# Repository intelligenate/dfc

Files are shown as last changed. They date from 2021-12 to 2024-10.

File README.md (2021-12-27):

# DFC - Data Fitness Connector

Free your data! 

DFC allows the Peloton Bike to communicate with fitness watches, head units, and apps — a feature that’s not available on the stock Bikes. It reads power and cadence data in real-time, through a cable connected to your bike, and broadcasts them wirelessly to nearby devices including those built around platforms like Zwift and Garmin. This lets you enjoy the built-in functionality of your bike while simultaneously utilizing features and services that depend on third-party platforms.

* Supports two simultaneous wireless connections for connecting to both a wearable and app at the same time
* Wireless device firmware updates for future upgrades
* Open and expandable platform for adding new features down the line

This repository is the home to the open design files for DFC. 

DFC can be ordered from the [Crowd Supply page here](https://www.crowdsupply.com/intelligenate/data-fitness-connector) and more information on DFC can be found on [our website](https://intelligenate.com/dfc.html).

See the [User Guide](https://github.com/intelligenate/dfc/blob/main/docs/user-guide.md) for details on how to setup and use DFC.

# Notice

DFC is a product of Intelligenate, LLC. DFC is not affiliated with Peloton Interactive, Zwift, Garmin or any other company mentioned in this repository. All trademarks are the property of their respective owners.

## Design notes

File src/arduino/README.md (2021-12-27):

# IrieTron 3030 Arduino Notes

The IrieTron 3030 Arduino file is what the initial development of DFC was done with. It is made to use with the Adafruit Bluefruit Feather board with a MAX3222 RS-232 driver/receiver IC on a FeatherWing. The Arduino version is no longer in active development and is provided to others who may want to make their own data broadcaster.

# Schematic

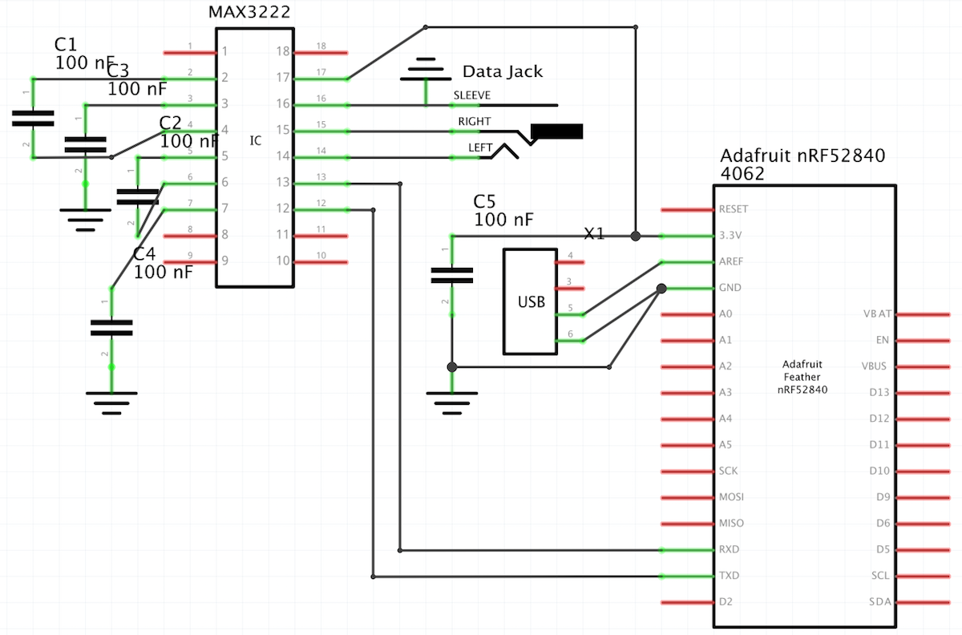
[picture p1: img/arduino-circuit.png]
arduino-circuit


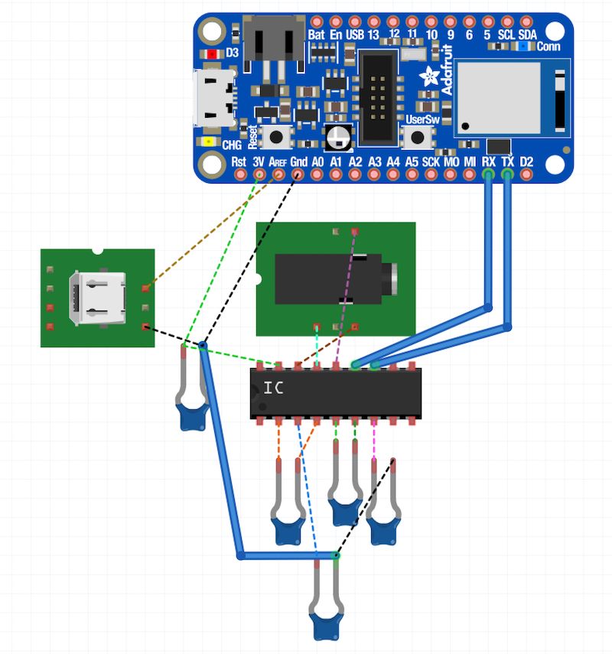
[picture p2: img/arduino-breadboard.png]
arduino-breadboard


# Bill of Materials

| Part | Quantity |
| --- | --- |
| 100nF Capacitor | 5 |
| Adafruit Bluefruit Feather | 1 |
| 3.5mm Jack | 1 |
| USB Connector | 1 |
| MAX3222 RS-232 driver/receiver IC | 1 |

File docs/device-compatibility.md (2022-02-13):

| Manufacturer | Model | Type | Power & Cadence | Speed & Cadence Only Beta | Notes |
| --- | ----- | ---- | --- | --- | ----- |
| Garmin | Fenix 6X, 6 Pro, 6 Saffire | Watch | Yes | Yes | |
| Garmin | Fenix 6, Fenix 6S | Watch | Yes* | | *Dropouts were causing issues with the base Fenix 6 models. Try [this update](https://github.com/intelligenate/dfc/releases/tag/power-cadence-beta.3) for a fix. See the [Firmware Updates](#firmware-updates) section below for details on updating. |
| Garmin | Fenix 5X | Watch | Yes | | |
| Garmin | Marq | Watch | Yes | | |
| Garmin | FR945 | Watch | Yes | | |
| Garmin | Venu, Insight | Watch | No | | These watches do not support reading power data from *any* manufacturer but speed and cadence should work |
| Garmin | Vivoactive 4 | Watch | No | Yes | These watches do not support reading power data from *any* manufacturer but speed and cadence should work |
| Garmin | FR645, FR245 | Watch | No | | These watches do not support reading power data from *any* manufacturer but speed and cadence should work |
| Polar | Grit X, Vantage | Watch | Yes | | |
| Cronos | Pace | Watch | Yes | | |
| Garmin | Edge 130, 530, 830 | Cycling Computer | Yes | Yes | |
| Stages Dash | M50, L50 | Cycling Computer | Yes | Yes | |

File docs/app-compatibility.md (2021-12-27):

| Application | Power & Cadence | Notes |
| --- | --- | ----- |
| Zwift | Yes | |
| TrainerRoad | Yes | |
| Sufferfest  | Yes | |
| Kinomap | Yes | |
| Wahoo | Yes | |

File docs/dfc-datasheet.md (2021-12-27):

# DFC Datasheet

DFC by Intelligenate

### Technical Specifications

- Built around an ARM Cortex-M4 32-bit processor with a 2.4 GHz transceiver
- 11 exposed GPIO pins in a breadboard- and IDC-compatible layout
    - 4 analog or digital pins
    - 7 digital-only pins
- 16 M-Bit QSPI external flash memory
- Two channels of bi-directional RS-232-to-TTL/CMOS conversion via MAX3222 IC
- I²C JST connector compatible with SparkFun's Qwiic or Adafruit STEMMA QT Connect System 
- SWD connections on the front and back of the board via Tag Connect footprints for firmware programming and debugging
- 20 V max to 3.3 V voltage regulator
- Two 3.5 mm stereo jacks connected to one another and to the RS-232 driver/receiver IC.
    - An off-by-default jumper allows the transmission of RS-232 data through the jacks
- Two USB Type-C connectors that allow DFC to be placed in-line with a USB cable operating at up to 20 V
    - This experimental, use-at-your-own-risk configuration allows you to branch off signals present in the USB cable—such and connect them to the processor
    - Configurable routes via jumper headers and solder pads for USB D+/- and SBU1/2

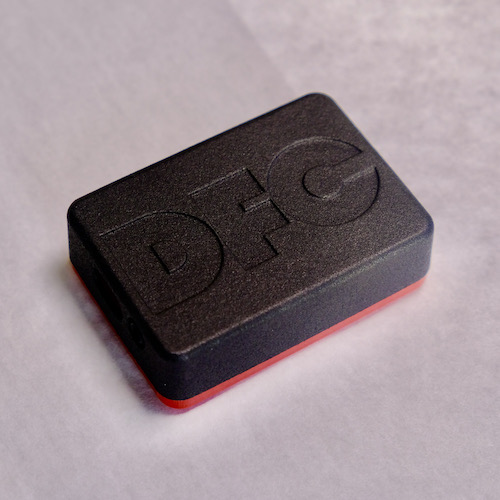
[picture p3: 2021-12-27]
img/dfc-production_sm.jpeg

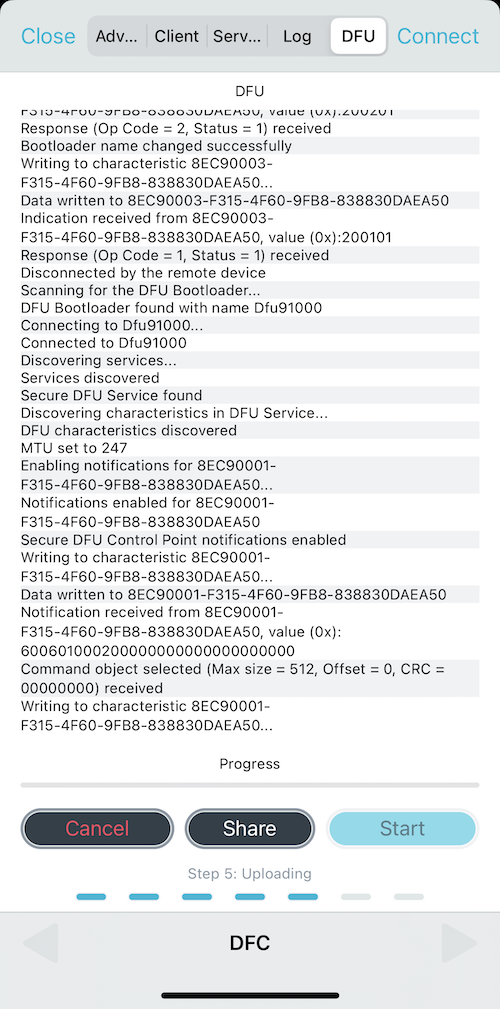
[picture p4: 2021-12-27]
img/firmware_update/DFC_fw_5.png

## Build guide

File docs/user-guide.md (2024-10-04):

# DFC User Guide

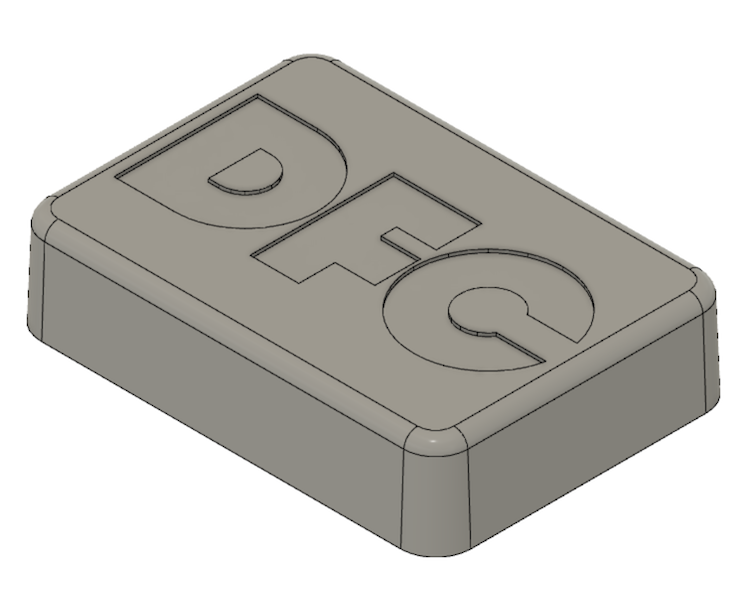
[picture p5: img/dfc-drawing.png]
dfc-drawing


# Features

DFC allows the Peloton Bike to communicate with fitness watches, head units, and apps — a feature that’s not available on the stock Bike. It reads power and cadence data in real-time, through a cable connected to your bike, and broadcasts them wirelessly to nearby devices including those built around platforms like Zwift and Garmin. This lets you enjoy the built-in functionality of your bike while simultaneously utilizing features and services that depend on third-party platforms.

* Supports two simultaneous wireless connections for connecting to both a wearable and app at the same time
* Wireless device firmware updates for future upgrades
* Open and expandable platform for adding new features down the line

# Connecting DFC to your bike

Hooking up DFC only takes a few minutes to get going and no cable-cutting or permanent modifications to the bike or tablet are necessary. Refer to the connection diagram for these steps.

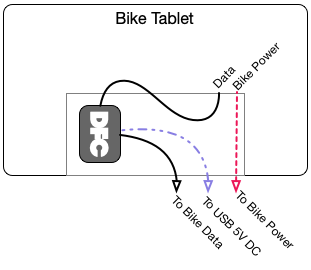
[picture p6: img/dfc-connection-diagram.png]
dfc-connection-diagram


1. Disconnect the data cable from the back of the tablet and plug it into either jack on DFC.
    1.  Two cables are on the back of the tablet – the one on the left is the data cable and the one on the right is the power cable. 
    2.  The data cable and power cable are held to the back of the tablet by a clasp that must be disengaged prior to removing the data cable.
    3.  DFC has two jacks that look similar to the ones you might use to plug in headphones, plug the data cable into either one.
2. Connect the provided short data cable between DFC and the data connection on the back of the tablet. Either data jack on DFC can be used for this connection.
3. Connect the provided long USB power cable to DFC.
    1. Either of the two USB-C ports on DFC can be used for this connection.
4. Connect the provided long USB power cable to a USB charging outlet. A USB charging outlet is not provided but most standard USB chargers such as those used to charge phones and other devices should work. 
    1.  NOTE: DFC must be powered with a USB-C to USB-A cable such as the one provided. It is not supported to work with a USB-C to USB-C cable.
    2.  DFC has two USB ports but only one is to be connected at a time. The multiple ports allow flexibility in placement and cable routing as well as future expansion options.
5. Recommended: Attach DFC to the back of your tablet with mounting tape or mounting putty. Use zip-ties to run the DFC power cable along the path of your bike's power cable for a clean look.
6. **Note: Make sure all the cables are pushed in fully before proceeding.**

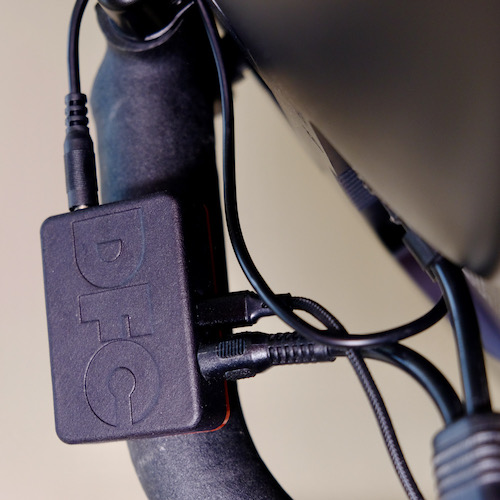
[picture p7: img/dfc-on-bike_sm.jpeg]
dfc-on-bike_sm


# Connecting to DFC with your device or app

1. Follow the directions from your specific application or device for pairing a sensor. See the [Compatibility Tables](#compatibility-table) for apps and devices that are known to work, or not, with DFC.
    1. DFC acts as a power meter and cadence sensor and will show up in the pairing screen or sensors section of the application/device you are connecting to. 
    2. For example, in Zwift in the Paired Devices menu: (1) click Power Source and select DFC, then (2) click Cadence and select DFC.
    3. For example, on a Garmin cycling computer or Fenix watch go to Settings > Sensor > Add Sensor and you will see DFC show up as a power sensor. Once selected your device will also read cadence from DFC with no additional setup required.
2. Once you do the initial pairing your device will connect to DFC automatically every time you start a ride.
3. Note: DFC only receives data when live power data is shown on the tablet screen. 
    1. Your connected device can start recording data before the class starts as long as the power/watts are displayed on the tablet screen. This allows you to string a few classes together and have them show up as one workout on your device.

# Troubleshooting

* DFC is not showing up on my device or app's pairing screen.
    * Verify that DFC is powered on. It will blink once per second for the first three minutes it’s powered on. You can see the blinking through the ports.
    * Some users have had trouble with using USB-C to USB-C power supplies. DFC draws so little power that they don't think anything is there and they shut down. For best results, use a power supply that works with the cable that DFC came with.
    * Some Garmin devices require a firmware update. [Try this update](https://github.com/intelligenate/dfc/releases/tag/power-cadence-beta.4) to fix it. See the [Firmware Updates](#firmware-updates) section below for details on updating.
* DFC is connected to my device or app but not showing any power data on my connected device.
    * Verify that all connections on DFC and your tablet are tight.
    * Verify that the screen on your tablet shows your power and other metrics.
    * Your tablet must be in a class or set to just ride a scenic or self-paced ride for DFC to receive data. 
* DFC is connected to my device or app but the tablet screen does not show any power data.
    * Verify that all connections on DFC and your tablet are tight.
    * Check the tablet screen for messages stating that there are loose connections. If so, recheck all connections. If there are no messages on the tablet screen then exit and restart the class you were doing.

# Compatibility Tables

Most modern devices and apps that support reading power data *should* work with DFC. Please note that DFC is not compatible with legacy devices that only support the the ANT+ protocol such as the Garmin Fenix 5 and Wahoo Roam v1 (2019). 

These tables are updated to show whether something is known to work with DFC (or not).

## Devices

| Manufacturer | Model | Type | Power & Cadence | Speed & Cadence Only Beta | Notes |
| --- | --- | --- | --- | --- | --- |
| Apple | Watch with WatchOS 10+ | Watch | Yes | Yes | Apple Watches with WatchOS 10+ work with DFC. [See here](https://www.dcrainmaker.com/2023/07/apple-watch-power-meters-support-everything-wanted.html) for how to set it up. |
| Garmin | Fenix 7, 7S | Watch | Yes | Yes | *A watch beta in early 2024 was causing issues with these. [This update](https://github.com/intelligenate/dfc/releases/tag/power-cadence-beta.4) fixes it. See the [Firmware Updates](#firmware-updates) section below for details on updating.* |
| Garmin | Epix (gen 2), Epix Pro | Watch | Yes | Yes | *A watch beta in early 2024 was causing issues with these. [This update](https://github.com/intelligenate/dfc/releases/tag/power-cadence-beta.4) fixes it. See the [Firmware Updates](#firmware-updates) section below for details on updating.* |
| Garmin | Fenix 6X, 6 Pro, 6 Saffire | Watch | Yes | Yes | |
| Garmin | Fenix 6, Fenix 6S | Watch | Yes* | | *Dropouts were causing issues with the base Fenix 6 models. [This update](https://github.com/intelligenate/dfc/releases/tag/power-cadence-beta.4) fixes it. See the [Firmware Updates](#firmware-updates) section below for details on updating.* |
| Garmin | Fenix 5X | Watch | Yes | | |
| Garmin | Marq | Watch | Yes | | |
| Garmin | FR945 | Watch | Yes | | |
| Garmin | FR265 | Watch | Yes | | *A watch beta in early 2024 was causing issues with these. [This update](https://github.com/intelligenate/dfc/releases/tag/power-cadence-beta.4) fixes it. See the [Firmware Updates](#firmware-updates) section below for details on updating.* |
| Garmin | FR935 | Watch | No | | |
| Polar | Grit X, Vantage | Watch | Yes | | |
| Cronos | Pace | Watch | Yes | | |
| Garmin | Venu, Insight | Watch | No | | These watches do not support reading power data from *any* manufacturer but speed and cadence should work |
| Garmin | Venu 3 | Watch | No | Yes | Garmin states that the Venu 3 supports power meters but it appears only ANT+ power meters are supported and DFC does not broadcast ANT+. The Venu 3 does support the speed and cadence beta firmware. See the [Firmware Updates](#firmware-updates) section below for details on updating. |
| Garmin | Vivoactive 4 | Watch | No | Yes | These watches do not support reading power data from *any* manufacturer but speed and cadence should work |
| Garmin | FR645, FR245 | Watch | No | | These watches do not support reading power data from *any* manufacturer but speed and cadence should work |
| Garmin | 735XT, Fenix 3 | Watch | No | | These watches only support the ANT+ wireless protocol which is not compatible with DFC |
| Garmin | Edge 130, 530, 830 | Cycling Computer | Yes | Yes | |
| Stages Dash  | M50, L50 | Cycling Computer | Yes | Yes | |
| Wahoo | Roam v2 (2022) | Cycling Computer | Yes | Yes | |
| Wahoo | Roam v1 (2019) | Cycling Computer | No | No | This device only supports the ANT+ wireless protocol which is not compatible with DFC |
## Apps

| Application | Power & Cadence | Notes |
| --- | --- | ----- |
| Zwift | Yes | |
| TrainerRoad | Yes | |
| Sufferfest  | Yes | |
| Kinomap | Yes | |
| Wahoo | Yes | |
| ROUVY | Yes | |

# Firmware Updates

Firmware updates are [located here](https://github.com/intelligenate/dfc/releases). To update the firmware or try out a beta release follow these steps.

1. Download the nRF Connect app for [iOS](https://apps.apple.com/us/app/nrf-connect-for-mobile/id1054362403) or [desktop](https://www.nordicsemi.com/Products/Development-tools/nrf-connect-for-desktop). Please note that the desktop version requires the use of a $10 USB dongle [available here](https://www.mouser.com/ProductDetail/Nordic-Semiconductor/nRF52840-Dongle?qs=gTYE2QTfZfTbdrOaMHWEZg%3D%3D). 
    * nRF Connect is a third-party app developed by the maker of the wireless chipset used in DFC. It allows you to perform wireless firmware updates on DFC.
    * Some users have reported issues using the [nRF app for Andriod](https://play.google.com/store/apps/details?id=no.nordicsemi.android.dfu&hl=en_US&gl=US&pli=1), given this we recommend the iOS app.

2. Download the firmware you want to install [from here](https://github.com/intelligenate/dfc/releases). 

    * Firmware releases are packaged as zip files. The latest, most compatible, releases are marked "Latest".

    * Releases marked "Pre-release" contain new features that may or may not work with some devices. 

    * If the new features on a pre-release build don't work with your device you can always go back to a stable release by downloading and installing the release marked "Latest".

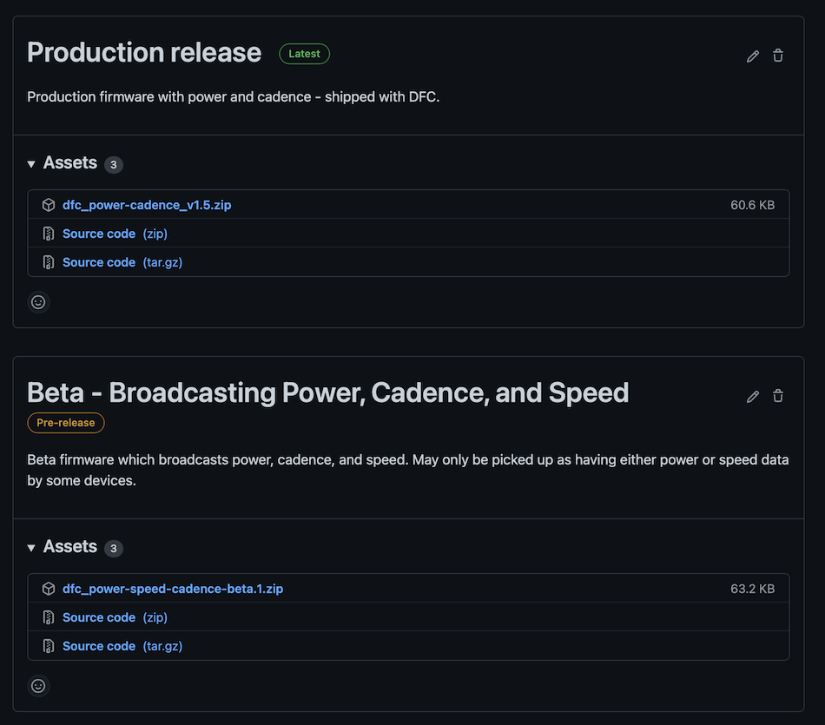
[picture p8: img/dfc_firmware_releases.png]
dfc_firmware_releases
    

3. Connect to DFC with nRF Connect.

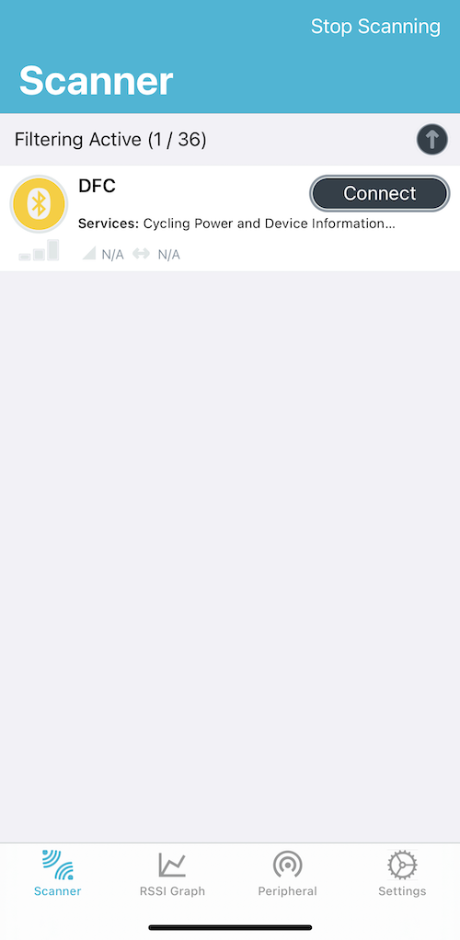
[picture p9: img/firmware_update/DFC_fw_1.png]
DFC_fw_1
    

4. Once connected go to the DFU tab on the top.

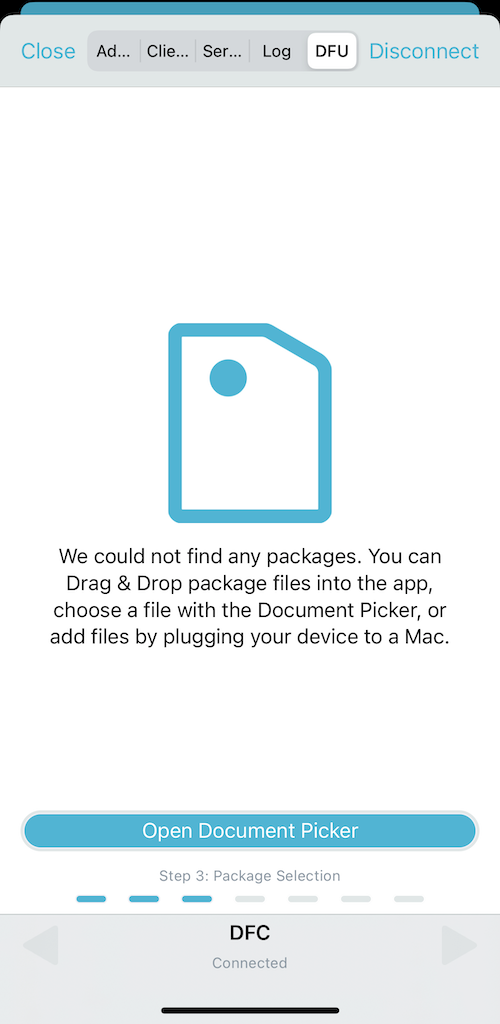
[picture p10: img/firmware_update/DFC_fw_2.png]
DFC_fw_2
    
    
5. Click Open Document Picker and select the firmware file downloaded earlier [from here](https://github.com/intelligenate/dfc/releases).

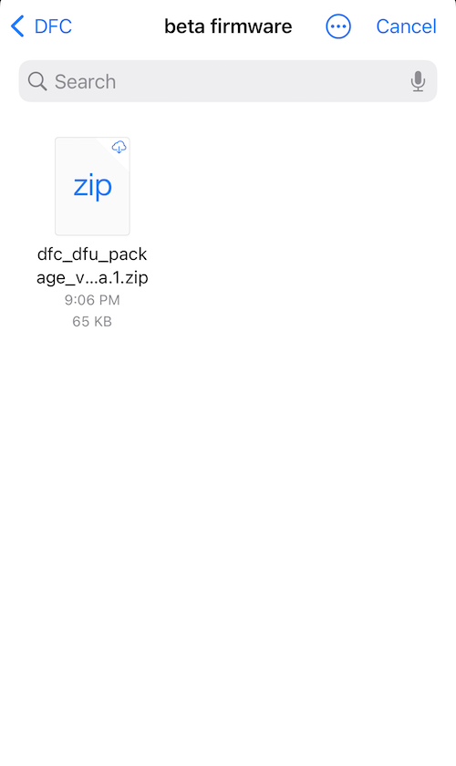
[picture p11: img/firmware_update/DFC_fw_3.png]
DFC_fw_3
    

6. After the file is loaded press Start to upload it to DFC.

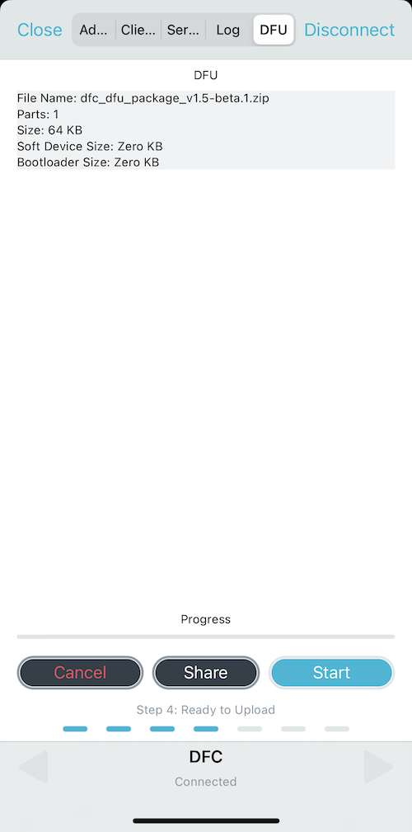
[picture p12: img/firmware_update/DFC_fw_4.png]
DFC_fw_4
    

7. After the update is completed you'll see the image below and can close nRF Connect.

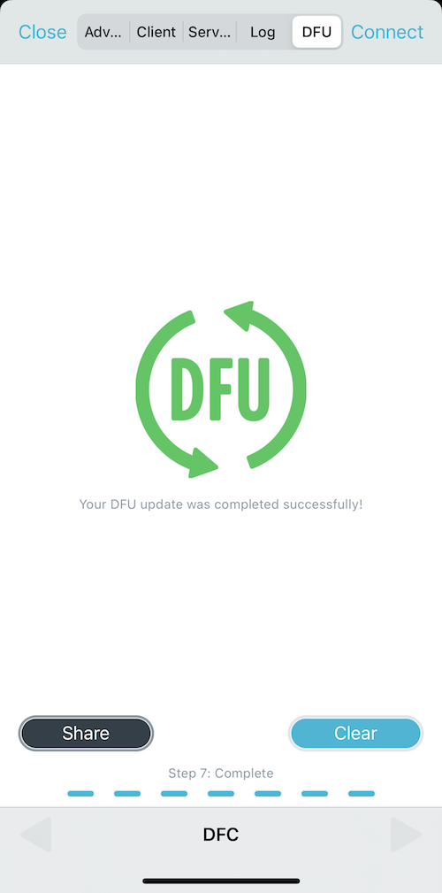
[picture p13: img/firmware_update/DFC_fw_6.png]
DFC_fw_6
    

# Upcoming Features

## Addition of speed sensor capability

We have a prototype of this working but testing with several fitness devices revealed some undesired behavior. Some devices only pick up either power data or speed data but not both.  We're working on this and will include an update once we get it working consistently across devices.

Adventurous users are welcome to try out the [beta releases here](https://github.com/intelligenate/dfc/releases). If you do so please report back what device you used and whether all the features worked. See the [Firmware Updates](#firmware-updates) section for details on how to update the firmware. After trying a beta release you can always revert back to the production release.

# FAQs

## Can I power DFC with the micro-USB connector on the back of the tablet?

While most USB-C to micro-USB cables don't allow for power going in that direction some users report that USB-OTG cables [such as this one](https://www.amazon.com/dp/B07KP6NTK7) may work. Additionally others have had success with using an [adapter like this](https://www.amazon.com/dp/B01LYYAOIE/) to plug into the back of the tablet, then use the cable that came with DFC to plug into that adapter. For those in Europe [this adapter](https://www.amazon.de/dp/B0BKPZD24M) has also been reported to work.

Down the road another option is that DFC can run on a coin cell battery but it's not optimized for that yet. It only lasts for a couple days instead of a few months so it's not advised to try it until it's working well. That would allow for a cleaner connection and no additional cord to run.

## Does DFC work with the Bike+?

DFC was designed to be compatible with the original Peloton Bike and is only supported for use with that model. Initial testing with the Bike+ has found that it's going to be infeasible at this time to support it.

# Notice

DFC is a product of Intelligenate, LLC and is designed and assembled in USA.

DFC is not affiliated with Peloton Interactive, Zwift, Garmin or any other company mentioned here. All trademarks are the property of their respective owners.

This user guide is released with a [CC BY-SA license](https://creativecommons.org/licenses/by-sa/4.0/).  

# Warnings, Regulatory Compliance, and Safety Information

## WARNINGS

* This product shall only be connected to an external USB power supply rated at 5-20V DC. Any external power supply used with DFC shall comply with relevant regulations and standards applicable in the country of intended use.
* In testing DFC no adverse incidents, to equipment or otherwise, connected to its use have been observed. In no event shall Intelligenate, LLC be liable for any direct, indirect, punitive, incidental, special consequential damages, to property or life, whatsoever arising out of or connected with the use or misuse of our products.

## INSTRUCTIONS FOR SAFE USE

To avoid malfunction or damage to your DFC please observe the following:
* Do not expose it to water or moisture while in operation.
* Take care while handling to avoid mechanical or electrical damage to the printed circuit board and connectors.

## COMPLIANCE INFORMATION

DFC complies with the relevant provisions of the European RoHS Directive 2011/65/EU, 2015/863/EU and Radio Equipment Directive (RED) 2014/53/EU. In common with all Electronic and Electrical products DFC should not be disposed of in household waste. Alternative arrangements may apply in other jurisdictions.

## FCC Statement

This device complies with part 15 of the FCC Rules. Operation is subject to the following two conditions: (1) This device may not cause harmful interference, and (2) this device must accept any interference received, including interference that may cause undesired operation.

## ISED Statement

This device complies with Industry Canada license exempt RSS standard(s). Operation is subject to the following two conditions: (1) this device may not cause interference, and (2) this device must accept any interference, including interference that may cause undesired operation of the device. 
Le présent appareil est conforme aux CNR d'Industrie Canada applicables aux appareils radio exempts de licence. L'exploitation est autorisée aux deux conditions suivantes: (1) l'appareil ne doit pas produire de brouillage, et (2) l'utilisateur de l'appareil doit accepter tout brouillage radioélectrique subi, même si le brouillage est susceptible d'en compromettre le fonctionnement. 

# SICHERHEITSANWEISUNGEN 

## WARNUNGEN UND HINWEISE 

* Dieses Produkt darf nur an eine externe Stromquelle mit einer Nennspannung von 5-20 V Gleichstrom. Alle mit dem DFC verwendeten externen Stromquellen müssen den betreffenden Vorschriften und Regelwerken des Nutzungslandes entsprechen. 
* Beim Testen von DFC wurden keine nachteiligen Vorkommnisse an Geräten oder auf andere Weise im Zusammenhang mit seiner Verwendung beobachtet. In keinem Fall haftet Intelligenate, LLC für direkte, indirekte, strafrechtliche, zufällige oder besondere Folgeschäden an Eigentum oder Leben, die sich aus oder im Zusammenhang mit der Verwendung oder dem Missbrauch unserer Produkte ergeben.

# RICHTLINIEN FÜR DEN SICHEREN GEBRAUCH 

Bitte halten Sie sich an die folgenden Anweisungen, um Fehlfunktionen oder Schäden an Ihrem DFC zu vermeiden: 
•   Setzen Sie das Gerät nie Wasser oder Feuchtigkeit aus und setzen Sie es nicht auf einer leitenden Oberfläche ab, während es in Betrieb ist. 
•   Seien Sie bei der Arbeit mit dem Gerät und dessen Handhabung vorsichtig, um mechanische oder elektrische Schäden an der Leiterplatte und an den Anschlüssen zu vermeiden. 

## COMPLIANCE-INFORMATIONEN

Das DFC entspricht den relevanten Bestimmungen für die europäische Union RoHS Directive 2011/65/EU, 2015/863/EU & Radio Equipment Directive (RED) 2014/53/EU. Wie alle anderen Elektro- und Elektronikprodukte (EEE) auch, darf das DFC nicht als Hausmüll entsorgt werden. In anderen Gesetzgebungen können alternative Regelungen gültig sein.
<hr>

CE_FCC

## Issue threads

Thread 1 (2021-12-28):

Beta Firmware - Feedback Report

htims05, 2021-12-28:
Hi - I tried the beta firmware to see if my watch would pick up the speed from the peloton.  Sorry to report but in my case the beta firmware seemed no different than the latest production version.  Meaning it still showed cadence and power but not speed.  This was using a Coros Pace 2 Watch as well as the Wahoo Fitness app on iOS (ver 14.8.1).

I'm not sure if this is the correct spot to post this but it looked like the only place to post feedback.

DangerP6, 2021-12-29:
On the production software, it passed the power data with no issues, however there was  no speed/distance data passed from the DFC/Peloton though the Garmin Fenix 6 watch. Thanks!

LeitoRodz, 2021-12-29:
Hi there,

Happy to report that power and cadence reports without issues on both production and beta FWs. No success on getting speed on the pre-released version.

Device: Garmin Forerunner 945
Software Version (Garmin device): 8.20 (28b18b9)

doudar, 2021-12-30:
A lot of BLE ftms devices don't report speed because real world speed is a product of your weight, rolling resistance, incline and drag. It's typically up to the app you are using i.e. Zwift to calculate the speed.

melissalee08, 2021-12-31:
Fenix 6S giving only speed and cadence after beta firmware update. Garmin software version 20.

veneman, 2021-12-31:
Thanks for sharing what's worked on the beta firmware.

What we've seen with the beta is that Garmin devices pick up either the cycling speed and cadence profile or the cycling power and cadence profile but not both.

The power meter profile spec allows for adding in the speed data as well but when we tried that it only worked for Wahoo devices. The fitness machine service spec allows for broadcasting power and speed so that'll be the next one to try. We'll send an update when that's ready to test. 

As @doudar mentioned, real world speed depends on many things. Since speed on an indoor bike is kind of made up we just matched it closely to what the bike displays as the speed at a given power/watts.

canuk-1, 2022-01-02:
Beta worked perfectly with Forerunner 745. No speed but not a surprise per above.

mkgraham82, 2022-01-03:
Thanks Jason for the great follow up.  New hardware has its bugs in the real world.  I tried the beta as well and power and cadence showed up.  No speed.  Would it be an issue to have metric speed in km/h?

Happy to have no issues with dropouts.

drewbiedoo, 2022-01-14:
Hi, just loaded the beta-2 bits onto my newly received DFC.  I have a Peloton Bike and a Garmin Vivoactive 4.   Worked great!   Thanks for providing this firmware update, as the release on the device wasn't recognized at all.   Interestingly, I also tried my Garmin Edge 510 and it would not recognize either version - I had hoped it would recognized power, which garmin has intentionally hobbled on the Vivoactive 4.   The good news is the Peloton Bike power isn't that accurate, so I'm not missing all that much.   Good luck with the venture, I really like this idea & implementation.

nwkandler, 2022-01-14:
Just a data point- I'm using a Fenix 6 Sapphire (19.2) and have had no problems - everything working great. Thank you - getting 'credit' with the power info in the Garmin ecosystem has been a huge improvement!

Harti-801, 2022-01-20:
Polar Vantage V, DFC with beta.1
Power, Cadence and Speed will be received by the watch. But there is a minor issue to the speed value. It is approximately 5 % lower as on the Peloton.
However I am really happy to own the DFC.

TJBoyle1, 2022-03-05:
I want to highlight an issue I'm not seeing anywhere else.  I am trying out the Speed & Cadence beta software connected to a Garmin Forerunner 745.  I'm getting both speed and cadence data just fine from my Peloton Bike (although I had to set the wheel size to 2115 mm to get distance to come out right).  But I also have an elliptical machine nearby that is fitted with Wahoo speed and cadence sensors.  When I try to use the Elliptical, I get no data unless I unplug the DFC on the Peloton.  It seems the DFC is broadcasting continuously whenever it has power, even if the Peloton has not been in use for hours, or days.  Somehow, the DFC is overiding the ANT+ connection of my Wahoo sensors to my Garmin 745. (I use the bluetooth connection for an app on my phone.)  Since Garmin does not allow the user to select or deselect sensors based on activity (a well-known deficiency), I seem to have no option but to unplug the DFC every time I want to use the elliptical. I'm not a watch watcher during an activity, so If I forget to unplug the DFC, I can get a long way into my elliptical workout with no data . This issue would disappear if the DFC stopped transmitting after some period of no activity coming from the Peloton.

drewbiedoo, 2022-03-05:
I'm seeing the always broadcasting behavior as well. Most sensors only Broadcast when there is activity and then a short period after.  The dfc just keeps sending. It would make sense to implement a sleep function on the radio when data is at 0 for some period of time.

veneman, 2022-03-07:
@TJBoyle1 Thanks for sharing the details on your use case. I can understand the frustration as I've run into a similar issue when I have one DFC plugged in on the workbench for testing and then I go to start a ride on the bike which has another DFC attached. I then have to dig into the sensor menu on my watch and disconnect from one of them.

We considered making it only advertise when it receives a signal from the bike but decided against it to make connecting to it more seamless. DFC advertises all the time so that it's quick and easy to connect it as soon as you're near the bike instead of having to wait until you have a class queued up. The bike only sends the signals that DFC picks up on when it's in a biking activity and showing the metrics on the display. Waiting until that data is there would mean a few extra seconds before you'd be able to connect to it. That's the tradeoff that drove the design as it is.

That being said, a future update may address your situation. DFC has the option to run on battery but it's not optimized to run for long at this time. To be more power efficient we'd wait for a signal and then start the radio. That's essentially what other battery powered sensors do. We don't have a timeline for this but it is on our list for a future update.

acousticbiker, 2022-12-29:
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

Any updates on whether the fitness machine spec worked or any other potential solutions to allow speed, cadence, and power?

only-chrisbh, 2023-01-14:
+1 to the last comment by Accousticbiker. Any update on getting the speed and/ or distance data yet?

acousticbiker, 2024-01-02:
Happy New Year! Just checking back to see whether any progress made on the being able to report speed along with cadence and power?

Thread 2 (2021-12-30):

Garmin Fenix 6 Connection Drops

canuk-1, 2021-12-30:
Hi - super happy to get our production DFC.

It is working flawlessly with Garmin Forerunner 945 (ie. getting power and cadence).

Garmin Fenix 6s successfully connects but connection drops in and out continuously thru the ride (functioning duty cycle of about 10%). Have tested this over multiple rides. Any thoughts?

Thanks!

melissalee08, 2021-12-31:
Experiencing similar issues with Fenix 6s. I do wonder if this is because my notifications during activity were turned on. My watch kept going off with group chat notifications and it seemed to coincide with the connection dropping/not picking up power. My previous ride didn't seem to have as severe connection drops.

I've turned off notifications during activity and will report back tonight or tomorrow when I get the chance to do another workout.

veneman, 2021-12-31:
Thanks for letting us know about this. The Fenix 6X Pro is what we've tested DFC the most with and we haven't seen any dropouts as described. We'll keep this open to gather info on what may be the root of this.

Any additional information like the Fenix firmware and what devices you have connected to the watch as well as what the watch is connected to would be helpful. E.g. Fenix software version 19.20, connected to iPhone, connecting to a Viiiiva heart rate monitor via ANT.

canuk-1, 2022-01-01:
Thanks Jason!

We will confirm we are on the latest firmware, turn off all other sensors and give it a whirl.

Thanks for you attention on this and Happy New Year!

Thanks, Chris

Chris Voice
Engage Selling Solutions Inc
www.EngageSelling.com
613-730-7700 x113 | Toll Free: 1-877-364-2438

________________________________
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

melissalee08, 2022-01-02:
Updates on my end:
Turned off in-activity notifications, no difference. I don't have any other sensors except Bluetooth headphones, which brings me to...

I did a ride on 12/29 and connection was good. There were some drops but nothing crazy. The software on my Fenix updated that night, and I also installed the Speed/Cadence beta the same night (I think). My power drop issues started after I reinstalled the original firmware. Not sure if canuk-1 had reinstalled the original firmware after trying out the Beta. If so, that might be the key?

canuk-1, 2022-01-02:
Hi there.

As of this AM, Fenix 6s continues to not stay connected:
- The Fenix firmware is the latest (v19.20; v20.0 was yanked).
- The DFC is the firmware as shipped
- No other sensors or bluetooth devices are connected (apart from on-board).
- The DFC successfully connects
- The cadence/power drops in and out (mostly out).

The Forerunner 745 continues to work flawlessly. Connection to DFC turned off when the Fenix was used per above.

Jason - I'm happy to test the Beta if you think that would be a meaningful test case.

doudar, 2022-01-02:
@veneman , if the Fenix is connecting via BLE, it sounds possible that it’s getting connection parameters that it’s incompatible with.

For the ESP-32 we can set connection timeouts and expected time between tx intervals like this:

https://github.com/doudar/SmartSpin2k/blob/ceefb349b6f914751ff2aa509d2bc6c06047ea33/src/BLE_Common.cpp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

Stoobiedoo, 2022-01-02:
Hi,
I'm using a Fenix 5X with no dropouts.
Software Version 17.30 (4769c95)
Paired with HRM-Pro Software 7.4
Stock, as shipped, DFC firmware.
I turn off my phone Bluetooth while riding because my headphones seem to preferentially go to the phone instead of Peloton. Not sure if that has an impact of Bluetooth connection stability.

veneman, 2022-01-02:
@melissalee08 Thanks for providing those details. Installing the beta then going back to the production shouldn't make a difference. I'll double check again but I've done that before and the machine code ends up being bit-for-bit identical as if it was a fresh install.
It's curious you mention that you had no issues with the cadence though. The cadence and power are always sent together so it's puzzling how one could be fine but not the other.

@canuk-1 Thanks for the details. You can keep using the production firmware since the beta one doesn't add anything for Garmins.
Are you noticing both cadence and power drop out at the same time on the Fenix?
Have you tried using both the Forerunner and Fenix at the same time? DFC will connect to two devices simultaneously (that's what I usually do) and I'm curious if that changes anything in your case.

@Stoobiedoo Thanks for providing the usage report. I'll add the 5X to the compatibility table.

@doudar Thanks for pointing to the connection parameters. We're running with the nRF5 SDK and have the connection parameters set based on one of the examples as follows:

```c
#define MIN_CONN_INTERVAL               MSEC_TO_UNITS(500, UNIT_1_25_MS)            /**< Minimum acceptable connection interval (0.5 seconds). */
#define MAX_CONN_INTERVAL               MSEC_TO_UNITS(1000, UNIT_1_25_MS)           /**< Maximum acceptable connection interval (1 second). */
#define SLAVE_LATENCY                   0                                           /**< Slave latency. */
#define CONN_SUP_TIMEOUT                MSEC_TO_UNITS(4000, UNIT_10_MS)             /**< Connection supervisory timeout (4 seconds). */
#define FIRST_CONN_PARAMS_UPDATE_DELAY  APP_TIMER_TICKS(5000)                       /**< Time from initiating event (connect or start of notification) to first time sd_ble_gap_conn_param_update is called (5 seconds). */
#define NEXT_CONN_PARAMS_UPDATE_DELAY   APP_TIMER_TICKS(30000)                      /**< Time between each call to sd_ble_gap_conn_param_update after the first call (30 seconds). */
#define MAX_CONN_PARAMS_UPDATE_COUNT    3                                           /**< Number of attempts before giving up the connection parameter negotiation. */
```

That gives it a range of .5s to 1s which seems pretty wide. It's up to the central device (i.e. the watch or app) to set the connection parameters if the provided ones are not compatible. I'll see what it gets set to across a few different devices.

melissalee08, 2022-01-03:
@veneman
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

Yep. I thought it was strange too. You can see a slight drop near the 18:18 mark but otherwise the cadence seems to be mostly there. There is some variance with the output on my Peloton but that is to be expected anyway.

doudar, 2022-01-03:
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

There could be a chance that FIRST_CONN_PARAMS_UPDATE_DELAY is too long for the for the watch defaults and the update connection parameters routine isn't getting called prior to the watch's default CONN_SUP_TIMEOUT. So it drops the connection.

I might suggest lowering FIRST_CONN_PARAMS_UPDATE_DELAY to 1000ms . I don't see an issue with lowering it at least. Typically you won't have problems with trying to set the connection parameters anytime after you've connected and sent one broadcast.

canuk-1, 2022-01-03:
Completed test with both Garmin 6s and Forerunner 745. Unfortunately it showed that both experience drop-outs - it's just that its better on the 745. Video of test at: https://youtu.be/0bwCW-MsGnc.

It may be unrelated but I did install the beta software and the nRF Connect app also regularly lost connection to the DFC.
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
htims05, 2022-01-10:
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

@veneman I used the latest beta today on a 45 min ride with my Coros Pace 2. Almost feels like it has more drops than production...note the green speed graph with all the zeros. Cadence I'm not sure why it doesn't go to the end of the ride - that's what the production version does, power and cadence not fully recorded (unless Coros is just shortening the graphs to cover the dropouts).

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

veneman, 2022-01-11:
@htims05 Thanks for the report on that. Yours is the only non-Fenix 6 that's reported dropouts like this and you also mentioned trouble with the Wahoo app. I'll run a longer test with the Wahoo app and see how it goes.
FWIW, before releasing the speed and cadence beta I did a test of a simulated ride going to a Garmin Edge 130 and didn't see any issues.
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

htims05, 2022-01-11:
@veneman interesting. So I decided to reset the watch and the DFC to production to see if that changes anything. But now the DFC is giving this error when trying to go back to production firmware.

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

htims05, 2022-01-11:
@veneman interesting.  I'll reset the watch and the DFC back to production and see it that changes anything.

htims05, 2022-01-12:
> @veneman interesting.  I'll reset the watch and the DFC back to production and see it that changes anything.
>
> For what it's worth the Coros is using Bluetooth 4.2

 No luck. I reset the watch and DFC and it still drops. You can see the power or cadence on the watch just disappear for 5-10 seconds every few minutes.

veneman, 2022-01-13:
Just posted a new [power and cadence beta](https://github.com/intelligenate/dfc/releases/tag/power-cadence-beta.2) that updates the initial connection parameters by giving them a very wide range, changes the `FIRST_CONN_PARAMS_UPDATE_DELAY` to 1000ms, and adds a call to update connection parameters when a request from a device is received.
No issues were seen in either a simulated or live test connecting to a Fenix 6X and Zwift.

mkgraham82, 2022-01-13:
@veneman uploaded your new prerelease this morning and rode for 45 mins.  Absolutely no drops.  Looks good!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

melissalee08, 2022-01-13:
Installed the update yesterday and still getting dropouts. Strange that cadence is (still) doing ok. On the watch if there was no power data there was no cadence data either.
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

FTR I am on a Fenix 6S, software version 2.0. no other sensors connected to the bike. Watch was connected to my phone with notifications turned off during activity.

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

canuk-1, 2022-01-14:
I'm afraid that likewise the new Beta did not fix the dropouts on our Fenix 6s. Forerunner 745 continues to do great unless both are connected at the same time - then the FR745 continually drops as well.

veneman, 2022-01-17:
Thanks for trying the beta out. To better debug this I have a new Fenix 6 on the way to test with. That should help get to the bottom of this faster.
@melissalee08 That's strange that the cadence data looks like it's there but not the power. Both of those are always sent together so if one is there the other should be too. The cadence should look more stochastic like below. I'm guessing that it's interpolating between the times that it gets data.
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
.

veneman, 2022-01-20:
@canuk-1 @melissalee08 @htims05
Just posted [an update](https://github.com/intelligenate/dfc/releases/tag/power-cadence-beta.3) that fixes the dropouts on a Fenix 6 in my testing.

Here's the details: In my initial testing with a Fenix 6 with the production firmware on DFC I saw the same kind of dropouts others have seen with the 6. The NRF SDK error was 0x08 which is a BLE_HCI_CONNECTION_TIMEOUT and is related to not receiving data from the watch. Others seeing that error had success changing the clock source that the microcontroller uses and, voila, that did it!

The clock was set to use the external crystal oscillator and wasn't working for the 6 when set to the oscillators accuracy of 20PPM. Setting it to 100PPM did work when just the watch was connected but when also connecting to Zwift it started dropping out again. Setting it to the internal clock seemed to work fine with both connected and I didn't see any dropouts in over an hour.

Using the internal clock uses slightly more power but won't matter with it powered via USB.

melissalee08, 2022-01-21:
Looks good! Thanks @veneman!
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

canuk-1, 2022-01-23:
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

Thanks so much! Confirmed working on Fenix 6s. Now do you get to buy a Fenix 7?

Hopefully there are no objections but I will mark this closed.

htims05, 2022-01-25:
>

I know this is now closed but also wanted to confirm that it is working on a Coros Pace 2 as well.

Closed 2022-01-23.

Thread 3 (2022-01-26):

Enabling Indications Failed

btbpsm, 2022-01-26:
I am unable to upload the original firm to DFC. I successfully uploaded dfc_speed-cadence-beta but would like to return to the original firmware. I get the error Enabling Indications Failed.

btbpsm, 2022-01-26:
I should have known better, I rebooted my phone (the device I am using to connect to the DFC) and I was able to upload the original firmware.

Closed 2022-01-26.

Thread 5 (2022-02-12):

Garmin Fenix 5 Plus dropped

Adanielcs, 2022-02-12:
My Fenix 5 plus worked once and now won’t find the sensor.  I loaded the update.  Oddly, sometimes when I’m done with my ride I will get a notification on the watch that power is connected.
How can I make the connection when it will be useful?
Right now, this isn’t working.

veneman, 2022-02-13:
Do you happen to know which update you tried? The [latest update](https://github.com/intelligenate/dfc/releases/tag/power-cadence-beta.3) released a few weeks ago has fixed dropouts for other devices.

Adanielcs, 2022-02-13:
I did the one targeted at garmin dropouts.If there is a new one I will try again. Sent from my Verizon, Samsung Galaxy smartphone
-------- Original message --------From: Jason Veneman ***@***.***> Date: 2/13/22  12:49 PM  (GMT-05:00) To: intelligenate/dfc ***@***.***> Cc: Adanielcs ***@***.***>, Author ***@***.***> Subject: Re: [intelligenate/dfc] Garmin Fenix 5 Plus dropped  (Issue #5)
Do you happen to know which update you tried? The latest update released a few weeks ago has fixed dropouts for other devices.

—Reply to this email directly, view it on GitHub, or unsubscribe.Triage notifications on the go with GitHub Mobile for iOS or Android.
You are receiving this because you authored the thread.Message ID: ***@***.***>

veneman, 2022-02-13:
A couple updates were released to try to fix the dropout issue. Give the latest one a try to see if that works.

btbpsm, 2022-02-13:
I had a very similar symptoms and found that the dfc was losing power. I was powering the dfc from the tablet and the USB connection would loosen during my ride. With the known drop issue and the problem being intermittent I assumed it was dropping. It is worth checking if your are powering from the tablet.

Good luck with your troubleshooting

Adanielcs, 2022-02-19:
The update did not help.  Power is not the issue, because the unit connects to my iPad for zwift.
It will not connect to Fenix 5 plus still.

veneman, 2022-03-07:
It's good to hear that it works with Zwift for you but discouraging that the update didn't fix it. I've heard from a Fenix 5X user that DFC works well for them and was hoping the update created for Fenix 6 users would fix yours.

Can you confirm that you tried the latest [power-cadence-beta.3](https://github.com/intelligenate/dfc/releases/tag/power-cadence-beta.3) update? Prior updates as well as the [speed-cadence-beta.1](https://github.com/intelligenate/dfc/releases/tag/speed-cadence-beta.1) update, which gives the option to use DFC as a speed and cadence sensor, do not have the timing fix that the power-cadence-beta.3 does.

If the update is not working for you please reach out via the [contact info](https://intelligenate.com/#about) on our website to discuss next steps.

Closed 2022-08-30.

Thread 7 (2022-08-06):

Can’t get it working

Solace2020, 2022-08-06:
Hi there. I can’t seem to get it working. The resistance and wattage numbers won’t show on the bike or the garmin paired with the dfc. Everything is plugged in - I’ve triple checked. Any tips?

ragemarkus, 2022-08-20:
You have the start a ride on the peloton to make the stats available to the dfc.

veneman, 2022-08-30:
Hey, sorry to hear you're having trouble. As mentioned above, you first have to be in a class or just ride for the data to be present for DFC. If you've done that and the numbers still aren't showing on the bike that may be an issue with the cabling. Send an email to support [at] intelligenate.com and we can help figure this out.

Closed 2022-12-13.

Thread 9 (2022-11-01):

Not working after recent Peloton update

melissalee08, 2022-11-01:
I updated my Peloton firmware today and the unit has stopped working - it is not detecting metrics, even when the ride has started and I am pedaling. Unplugged, replugged, restarted, etc. Anyone experiencing the same issue?

tonylchang, 2022-11-01:
I’ll try and let you know! Just hit update on my bike.

tonylchang, 2022-11-01:
The DFC is still working for me after the latest peloton update. My Garmin was able to receive power and cadence data for my ride.

veneman, 2022-11-02:
I don’t have any issues with apps or my Garmin with the latest update NQ.220527.A. I’m puzzled as to what could be causing the trouble. You’ve tried all the things I would have suggested.

btbpsm, 2022-11-02:
which firmware release are you using?

melissalee08, 2022-11-02:
I did the cable dance again this morning and it worked. Weird.

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

Closed 2022-11-07.

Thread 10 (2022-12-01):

Is it still impossible to transmit speed, power and cadence at the same time?

tzm41, 2022-12-01:
Just purchased one from Crowd Supply. But it doesn't look like transmitting all three data has been working?

tzm41, 2022-12-12:
Alright I guess there's no active effort into this anymore. Time to cancel my order unfortunately...

veneman, 2022-12-13:
It's definitely still under active development and we've got bunch of new devices being built right now. We had to put the combo power and speed work on the back burner to get the next production run going but are trying some new multi-metric things now.

Closed 2022-12-13.

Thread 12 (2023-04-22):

PeloMon as info to help get Speed

Stoobiedoo, 2023-04-22:
Would any of the work done by Imran Haque be helpful in getting speed to work with the DFC?
https://ihaque.org/tag/pelomon.html
https://github.com/ihaque/pelomon

veneman, 2023-04-26:
We have a [beta release](https://github.com/intelligenate/dfc/releases/tag/speed-cadence-beta.1) that will broadcast speed and cadence together but not power. We were hoping to get DFC to appear as two separate sensors (power+cadence & speed+cadence) but haven't found a good solution for that. We're now working to make DFC appear as a "fitness machine" which allows sending speed, power, and cadence as one sensor.

Closed 2023-04-26.

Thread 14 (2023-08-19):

Unable to pair FR935

chipkent, 2023-08-19:
I am attempting to pair a FR935 on some new hardware.  The watch does not seem able to identify the device.

The troubleshooting docs indicate:
```
DFC is not showing up on my device or app's pairing screen.
* Verify that DFC is powered on. It will blink for the first three minutes it’s powered on.
```
There does not appear to be a light on my device.

Should I expect this device to work?

veneman, 2023-12-14:
Closing this out since we've resolved this offline. Unfortunately the FR935 does not appear to work with DFC. This is now noted in the [compatibility table](https://github.com/intelligenate/dfc/blob/main/docs/user-guide.md#compatibility-tables).

Closed 2023-12-14.

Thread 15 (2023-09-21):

Won’t pair with Garmin Venu 3

987664987, 2023-09-21:
Just received my device and was able to connect through wahoo app as a test but my garmin Venu3 doesn’t find it when searching for a sensor

planzi, 2023-10-11:
Got mine to work. You have to install the beta firmware on the DTC.

987664987, 2023-10-11:
Yes the beta speed/cadence update works but no power reading which supposedly the Venu 3 supports

Trebuin, 2023-10-11:
There currently isn’t a speed/power/cadence beta available yet.  I would love to have that or at least speed & power to try.  I’m thinking of seeing if it is possible to get two devices & have one pipe out speed & cadence & the second pipe out power & cadence.  Obviously that’s a more expensive choice but not as bad as buying power pedals.  Any news on Speed & Power?  I’m on the Fenix 7 which works great for everything & wouldn’t mind trying betas.

mwerner85, 2023-11-10:
Confirming some of these comments - I can get the beta Speed/Cadence firmware load to work with my Venu 3, but the base firmware and the beta Power/Cadence one doesn't seem to be recognized by the watch.

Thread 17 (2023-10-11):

What size wheel to set (Garmin)?

planzi, 2023-10-11:
The speed and distance values that show up in my garmin workout don’t match those on the peloton screen. I suspect I need to change the wheel size setting on the setup for the speed/cadence sensor on my garmin watch. Does anyone know the correct wheel size to set?

Trebuin, 2024-01-23:
> The speed and distance values that show up in my garmin workout don’t match those on the peloton screen. I suspect I need to change the wheel size setting on the setup for the speed/cadence sensor on my garmin watch. Does anyone know the correct wheel size to set?

I'm sorry no one has replied to this earlier:
The peloton programmed the speed with the resistance, not the actual cadence or distance the tires would realistically cover.  That means the distance needs programmed at the end after the event is over at least until we get speed sent through DFC.  The other option is to add the speed/cadence firmware & buy a power meter ($700ish).  I have though about purchasing a second DFC to see if I can set that one up for speed...that would be a lot cheaper than buying a power meter pedal.

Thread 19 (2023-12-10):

Power displaying 0

skofman, 2023-12-10:
I am using the Garmin Epix 2 watch with the DFC and getting power showing 0.
The power does show on the Peloton Bike screen going through the DFC and the DFC is paired to the watch.

Is there anything I can do to make it work?

veneman, 2023-12-13:
Sorry to hear you're having trouble. The Epix 2 should work fine, there's a number of others we've heard using it with DFC.

Here's a few things to try to get you up and riding:

- The first thing to check is that you have the "Bike" and not the "Bike+". DFC doesn't work with the Bike+.
- Verify that you're in a class or on the "Just Ride" screen for the data to be there. If the data is not on the screen it won't get sent to DFC.
- Have you tried connecting DFC to any other devices or apps? Kinomap or Zwift are pretty easy to get up and running quickly with DFC.
- Have you connected any other power meters to your Epix?
- Since the bike is showing the data it seems like the cabling is fine but you could try re-seating the cables and swapping data ports on DFC.
- When you power on DFC do you see a red light blinking through the ports for the first few minutes?
- What are you using to power DFC? It works best using the cable that it comes with it. Using USB-C to USB-C cables can cause issues since DFC draws so little power that some USB-C chargers shut off power to it.
- On your watch under DFC in Sensors does it say "Status Connected"?
- The Fenix 6s needs a special firmware to work and that's worth a try if nothing else works even though you have an Epix. The firmware can be updated by following the [directions here](https://github.com/intelligenate/dfc/blob/main/docs/user-guide.md) and using the firmware file at [this link](https://github.com/intelligenate/dfc/releases/tag/power-cadence-beta.3) to get you going.

theredwonder, 2024-01-20:
I'm having this same issue with my Epic Gen 2 and regular Peloton Bike. Checked and swap all cables. Watch shows DFC connected, but power shows as "- -".

theredwonder, 2024-01-22:
So the DFC is working with my other watch, Forerunner 265S, and it was working a week ago on my Epix Gen 2 (checked past workout). I am on Beta software on my Epix, which may have updated in the past week. Epix is currently running version 16.11. This might be the watch's fault.
Video of the behavior: https://photos.app.goo.gl/XohNS9UZGu7LbrqY9

theredwonder, 2024-01-23:
I reverted my watch back to a previous version of firmware and DFC is working as expected.

Trebuin, 2024-01-23:
I just read your post & ran a test on my fenix 7 on 16.11 & sure enough, it can’t hold a connection to DFC.  I’m going to submit a bug report in the Garmin forum very shortly.  I would appreciate anyone else to post there as well.  I’ll post the link once I upload it.  If we don’t get it fixed during this build…we lose DFC.

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

theredwonder, 2024-01-23:
@Trebuin , I'm a step ahead of you, upvote my bug report! https://forums.garmin.com/beta-program/fenix-7-series/public-beta-reports/i/public-beta-16-xx/16-11-epix-gen-2-not-receiving-data-from-bluetooth-power-meter

theredwonder, 2024-01-23:
> I just read your post & ran a test on my fenix 7 on 16.11 & sure enough, it can’t hold a connection to DFC.  I’m going to submit a bug report in the Garmin forum very shortly.  I would appreciate anyone else to post there as well.  I’ll post the link once I upload it.  If we don’t get it fixed during this build…we lose DFC.
> […](#)
> On Jan 22, 2024 at 9:51 PM -0600, theredwonder ***@***.***>, wrote: I reverted my watch back to a previous version of firmware and DFC is working as expected. — Reply to this email directly, view it on GitHub, or unsubscribe. You are receiving this because you are subscribed to this thread.Message ID: ***@***.***>

I went back to 15.77 on my Epix gen 2 and its holding a connection to the DFC just as expected.

Trebuin, 2024-01-23:
I should have added to that.  Mine is up if you want to upvote that as well…it’ll probably get merged.  It’s different watches at least.  I just upvoted yours to get some visibility.  Thanks!

https://forums.garmin.com/beta-program/fenix-7-series/public-beta-reports/i/public-beta-16-xx/power-cadence-meter-device-connection-no-longer-holds-a-connection-16-1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

Trebuin, 2024-01-23:
I’ll stay on beta releases to see if Garmin fixes it soon.
@Veneman - Do you think the power/cadence beta.3 build would be tied to this issue?  When I get time, I’ll update it.  I’m still hoping for a speed/power/cadence, or at least a speed/power firmware build…I have a cadence meter.
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

theredwonder, 2024-01-23:
@Trebuin you seem to be like minded! I've been hoping for the speed/power setting on the DFC since I got it as well :) (speed + power + cadence would be the dream)

Trebuin, 2024-01-23:
@theredwonder I've been debating getting a second DFC & seeing if I can flash it with a speed firmware...it would be a lot cheaper than flashing my current one with Speed/Cadence & buying a power pedal...those things cost a pretty penny.  I'll hold out a little longer for Veneman to possibly come up with another firmware.  He might end up coming up with a new board with two boards inside to do exactly the same thing I just recommended.

theredwonder, 2024-01-23:
> @theredwonder I've been debating getting a second DFC & seeing if I can flash it with a speed firmware...it would be a lot cheaper than flashing my current one with Speed/Cadence & buying a power pedal...those things cost a pretty penny. I'll hold out a little longer for Veneman to possibly come up with another firmware. He might end up coming up with a new board with two boards inside to do exactly the same thing I just recommended.

I have a set of Garmin Rally 200 pedals I was using before getting the DFC. I had been swapping them between my 3 bikes +  Peloton, but it was getting to be annoying so I got the DFC. I did use my Rally pedals to precisely calibrate the Peloton. It was giving me an extra 12% of power, which was nice on paper but didn't translate well in real world when comparing against my pedals (power zones all messed up).

Still hoping for the power + speed so I don't have to edit the distance in Garmin for every ride.

Trebuin, 2024-01-24:
So for those who are following, @theredwonder & I have both pushed tickets.  If you can, please bump each ticket.  Mine is up to 5 & his is up to 3 right now...the 5 being on the second forum page so hopefully we get a little visibility.  I'm trying to reach out to some at work to help bump it as well...the more, the better.

I tried bluetooth compatibility mode but even that didn't change anything.  I have not tried rolling the firmware to beta 3 yet but will start looking at that tonight.

veneman, 2024-01-25:
@Trebuin We've had another user with a Fenix 7 Pro do some testing with the power/cadence beta 3 and the speed/cadence beta but those didn't fix the issue so don't bother with that for now.

I have an Epix on the way to do some debugging with on my end. I'll report back what I find.

Thank you for submitting an issue with Garmin too.

Trebuin, 2024-01-25:
That’s not a problem.  We have a few people I work with who jumped on the bandwagon to help get this fixed.  My unit is obsessed with the Garmin watch & I’m surprised I have been as well.  Have a good night & thanks for a great device with the DFC!
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

veneman, 2024-02-01:
@Trebuin @theredwonder I have a fix working for this with a firmware update. I need to do a little more testing but expect to have a release out in a few days.
The latest Fenix and Epix betas send a pairing event that's not been called before and that was causing an error.

theredwonder, 2024-02-01:
Incredible!! Thank you for the update!

On Wed, Jan 31, 2024, 8:46 PM Jason Veneman ***@***.***>
wrote:

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

Trebuin, 2024-02-01:
Thank you!  This will probably be the first time there will be a bulk update for everyone unless Garmin pulls their change, if they pull it. I don’t know if their change is necessary.

Respectfully,
Sean R. McConnell
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

PipotronM, 2024-02-04:
Hello to the community!
Quick note to say that I'm seeing the same issue on the FR265s on beta 18.15.
Unfortunately I haven't found a way to downgrade firmware on the 265s so looking forward to hearing more about the DFC update (or Garmin pulling the change on the next version..)
Thanks everyone!

Trebuin, 2024-02-05:
Veneman posted the fix, Beta 4 works like a champ on my first try.

For those who want a video to follow to update, here you go:

https://youtu.be/JNuzTvyP7F8?si=ISCkpFrASZajjowB

Trebuin, 2024-02-05:
@veneman do you want us to post this fix to Garmin or hold off to see if they fix that new behavior?

theredwonder, 2024-02-05:
Any chance the "fix" Garmin might come up with could work inversely with the Beta 4 here?

veneman, 2024-02-05:
@Trebuin You found that quick! I was just doing a final test with an update from the Github release before posting here. Glad to hear it worked!

I'll post a comment on one of those Garmin forum pages stating what was done. The beta they released isn't doing anything "wrong" but it's not clear why they're now sending a new request for certain parameters which aren't used. There's nothing related to it as far as I can tell in their beta release notes. The fix for DFC was to ignore the request.

@theredwonder If they stop sending the new request it won't matter to DFC - it'll just work like it did before. The update I made doesn't change anything for devices that don't send that parameter request.

theredwonder, 2024-02-05:
Brilliant!! Great work. Its been a little longer than the "usual" cadence of 1 week between beta releases. I'll stick it out another week to see what Garmin comes up with.

PipotronM, 2024-02-05:
Thank you so much!
Beta 4 works great on FR265s, fixing the 0 power issue. (also, FR265 can be added to the compatibility table as good to go: power+cadence)

veneman, 2024-05-01:
Closing this as the update [posted here](https://github.com/intelligenate/dfc/releases/tag/power-cadence-beta.4) resolves the issue. See the [Firmware Updates](https://github.com/intelligenate/dfc/issues/19#firmware-updates) section in the user guide for details on updating.

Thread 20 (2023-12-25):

Does it work with a Garmin FR965?

mbolesta, 2023-12-25:
I didn’t see it listed on your compatibility table.

mbolesta, 2024-02-26:
I took and chance and bought one and it seems to work.

I installed the beta firmware though as at first I thought I was missing the cadence sensor (as it is combined with the power one).

Would love to also have speed but not sure if all 3 are possible with this hardware iteration.

Closed 2024-05-01.

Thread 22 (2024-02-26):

Apple Watch

rovo79, 2024-02-26:
Is the intention that my watch should be paired to the DFC device, or device running the cycling app(eg zwift)?

Currently it looks to be paired to DFC.

I cant find a way to maintain an HR data stream to zwift.

wcotis, 2024-02-26:
Try the Echo app on your iPhone https://www.echoheartrate.app/

veneman, 2024-05-01:
DFC can pair with both an Apple Watch and Zwift at the same time and send power and cadence data. For broadcasting heart rate you'll have to check out other resources such as the Echo app mentioned here.

rovo79, 2024-05-01:
I was able to sort it out, and get my heart rate sent to Zwift (on iPad) reliably.

DFC broadcasting from Peloton to iPad running Zwift.
Zwift Companion on Apple Watch sending heart data to Zwift Companion on iPhone, iPhone sending to iPad.

I finally realized they all need to be on the same wifi SSID to function and stay connected in Zwift. I have several SSIDs in my house that the devices roam across. Forcing them all on the same, makes it work.

Closed 2024-05-01.

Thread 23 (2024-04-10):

DIY Display

chadamodio, 2024-04-10:
Looking for instructions to build a diy display that shows the output (i.e: raspberry pi or Arduino) rather than buy some expensive watch or app subscription

veneman, 2024-05-01:
To build a DIY display your best option would be to start from the [Arduino version of DFC](https://github.com/intelligenate/dfc/tree/main/src/arduino).

Closed 2024-05-01.

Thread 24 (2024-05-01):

Power display empty - Garmin Edge v21.09 update

steveninmanCubs, 2024-05-01:
Hi all,

I've been talking to Garmin support and I can't figure out what is going on. For a couple of years, I pushed DFC data on my Peloton to my Garmin Fenix 6s Pro and it's always worked like a charm. In Feb, I bought a Garmin Edge 840 and I've been pushing to that (easier to see power tied to some workouts I'm doing than looking at my watch).

Last week, I got an alert that Garmin Edge updated to v21.09 and ever since then I can't get power data to show and the connection seems to drop in and out. I've reverted to using my Fenix 6s which is on 26.96 and it's been working fine.

Any ideas about things I could try to get the Edge working again? Should I back ou v21.09 on my Edge and go back to prior one? Are there any logs I can provide?

Thanks,
Steve

veneman, 2024-05-02:
An update to Fenix and Epix caused some similar issues earlier this year. [Try this update](https://github.com/intelligenate/dfc/releases/tag/power-cadence-beta.4) to fix it. See the [Firmware Updates](https://github.com/intelligenate/dfc/issues/24#firmware-updates) section in the user guide for details on updating.

steveninmanCubs, 2024-05-02:
That did it. Brilliant!! Something change with how Garmin is feeding the power data over Bluetooth?

Closed 2024-05-02.

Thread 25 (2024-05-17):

DFC not transmitting data anymore to Garmin Epix 2

Alexalas84, 2024-05-17:
DFC is not transmitting any cadence or power data to Garmin Epix 2. This started happening a couple of months ago.

veneman, 2024-05-17:
A beta update for certain Garmin devices (Epix (gen 2), Fenix 7, FR265,
and possibly others) was causing DFC to continually reset. The issue was
related to a parameter request from those devices for something that’s
not supported by DFC. DFC now ignores that type of request if it’s not
valid. 

The updated firmware is here
<https://github.com/intelligenate/dfc/releases/tag/power-cadence-
beta.4>. See the Firmware Updates
<https://github.com/intelligenate/dfc/blob/main/docs/user-
guide.md#firmware-updates> section in the User Guide
<https://github.com/intelligenate/dfc/blob/main/docs/user-guide.md> for
details on updating. Many other users have tested it and reported that
the fix works great for them and they're back in business.

On May 17, 2024, GitHub ***@***.***> wrote:
> DFC is not transmitting any cadence or power data to Garmin Epix 2.
> This started happening a couple of months ago.
>

—
Reply to this email directly, view it on GitHub
<https://github.com/intelligenate/dfc/issues/25>, or unsubscribe
<https://github.com/notifications/unsubscribe-
auth/ABPRUHLLBNEWKBIK6HO63BDZC2E4FAVCNFSM6AAAAABH44Y756VHI2DSMVQWIX3LMV43ASLTON2WKOZSGMYDGNRXGM4DSMI>.
You are receiving this because you are subscribed to this thread.Message
ID: ***@***.***>

Closed 2024-11-18.

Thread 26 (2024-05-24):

Connected but no data

Artmidd, 2024-05-24:
The dfc connected to garmin but not registering data.  Tightened all wires connected and unconnected powered on and off.  Do I need new dfc?

veneman, 2024-05-24:
Here’s a few things to check to help narrow down what may be causing issues.

* Has it worked before or is this the first time you’re connecting DFC to anything?
* What specific device is it that you're trying to connect?
    * [This table](https://github.com/intelligenate/dfc/blob/main/docs/user-guide.md#compatibility-tables) lists which devices are known to work with DFC.
    * An update for certain Garmin devices (Epix (gen 2), Fenix 6/7, FR265, and possibly others) was causing DFC to continually reset.
    * The updated [firmware that fixes the issue is here](https://github.com/intelligenate/dfc/releases/tag/power-cadence-beta.4). See the [Firmware Updates](https://github.com/intelligenate/dfc/blob/main/docs/user-guide.md#firmware-updates) section in the [User Guide](https://github.com/intelligenate/dfc/blob/main/docs/user-guide.md) for details on updating.
* Have you tried connecting DFC to any other devices or apps? Kinomap or Zwift are pretty easy to get up and running quickly with DFC.
* Try re-seating the cables and swapping data ports on DFC.
* When you power on DFC do you see a red light blinking through the ports for the first few minutes?
* What are you using to power DFC? It works best using the cable that it comes with it. Using USB-C to USB-C cables can cause issues since DFC draws so little power that some USB-C chargers shut off power to it.
* On your watch under DFC in Sensors does it say "Status Connected"?

Artmidd, 2024-05-24:
Hi thanks for getting back to me.  It's been working great for almost a year.  Nothing changed in the set up. It's hooked up to a peloton - first edition.  Not the plus. It's on a Fenix 7. I will try the firmware update though it may be too complicated for me! Have not tried connecting to other apps or devices. Tried re seating the cables. See the red light. Using the cord that came with it to power it. It does say status connected.  Just not getting the reading. I think it must be the recent garmin update.  I did notice that it goes in and out, so maybe that's the continual reset.  Was that a. Recent update from garmin that caused the issue?  Thanks again.  Art. On May 23, 2024, at 11:03 PM, Jason Veneman ***@***.***> wrote:
Here’s a few things to check to help narrow down what may be causing issues.

Has it worked before or is this the first time you’re connecting DFC to anything?
What specific device is it that you're trying to connect?

This table lists which devices are known to work with DFC.
An update for certain Garmin devices (Epix (gen 2), Fenix 6/7, FR265, and possibly others) was causing DFC to continually reset.
The updated firmware that fixes the issue is here. See the Firmware Updates section in the User Guide for details on updating.

Have you tried connecting DFC to any other devices or apps? Kinomap or Zwift are pretty easy to get up and running quickly with DFC.
Try re-seating the cables and swapping data ports on DFC.
When you power on DFC do you see a red light blinking through the ports for the first few minutes?
What are you using to power DFC? It works best using the cable that it comes with it. Using USB-C to USB-C cables can cause issues since DFC draws so little power that some USB-C chargers shut off power to it.
On your watch under DFC in Sensors does it say "Status Connected"?

—Reply to this email directly, view it on GitHub, or unsubscribe.You are receiving this because you authored the thread.Message ID: ***@***.***>

Artmidd, 2024-05-25:
Figured out the update and it worked.  Thank you!!On May 24, 2024, at 8:47 AM, ART MIDDLEMISS ***@***.***> wrote: Hi thanks for getting back to me.  It's been working great for almost a year.  Nothing changed in the set up. It's hooked up to a peloton - first edition.  Not the plus. It's on a Fenix 7. I will try the firmware update though it may be too complicated for me! Have not tried connecting to other apps or devices. Tried re seating the cables. See the red light. Using the cord that came with it to power it. It does say status connected.  Just not getting the reading. I think it must be the recent garmin update.  I did notice that it goes in and out, so maybe that's the continual reset.  Was that a. Recent update from garmin that caused the issue?  Thanks again.  Art. On May 23, 2024, at 11:03 PM, Jason Veneman ***@***.***> wrote:
Here’s a few things to check to help narrow down what may be causing issues.

Has it worked before or is this the first time you’re connecting DFC to anything?
What specific device is it that you're trying to connect?

This table lists which devices are known to work with DFC.
An update for certain Garmin devices (Epix (gen 2), Fenix 6/7, FR265, and possibly others) was causing DFC to continually reset.
The updated firmware that fixes the issue is here. See the Firmware Updates section in the User Guide for details on updating.

Have you tried connecting DFC to any other devices or apps? Kinomap or Zwift are pretty easy to get up and running quickly with DFC.
Try re-seating the cables and swapping data ports on DFC.
When you power on DFC do you see a red light blinking through the ports for the first few minutes?
What are you using to power DFC? It works best using the cable that it comes with it. Using USB-C to USB-C cables can cause issues since DFC draws so little power that some USB-C chargers shut off power to it.
On your watch under DFC in Sensors does it say "Status Connected"?

—Reply to this email directly, view it on GitHub, or unsubscribe.You are receiving this because you authored the thread.Message ID: ***@***.***>

VMUNIS, 2024-06-19:
@Artmidd I am having the same problem (Fenix 7). Can you walk me through how to do the update. This is on the Garmin watch, correct?

Trebuin, 2024-06-19:
> @Artmidd I am having the same problem (Fenix 7). Can you walk me through how to do the update. This is on the Garmin watch, correct?

https://youtu.be/JNuzTvyP7F8

That will walk you through the upgrade on ios

davidavallance1, 2024-06-26:
Happy to report that I installed the latest version of the firmware and I now have power and cadence.  This is for the Garmin 7x Pro.  I used the Android mobile DFU to complete the FW update.
Thank you!!

VMUNIS, 2024-06-28:
I tried to follow the video but it my app for the phone (Android) looks
nothing like the video. 🙃

Question: I'm trying to upgrade the firmware on the device over bluetooth,
correct?

Is there a way to connect the device to a computer and try it that way?

Can you give me step by step directions on how to do it?

Help! Lol! I miss my power data on my connect app.

On Tue, Jun 25, 2024, 6:42 PM davidavallance1 ***@***.***>
wrote:

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

Closed 2024-11-18.

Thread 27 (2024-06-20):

Fenix 6 Saffire Does Not Detect

TheWebRecluse, 2024-06-20:
I just purchased a Garmin Fenix 6 Saffire today for the purposes of using it with my Peloton and the DFC.
I have used DFC + Peloton via Zwift before though with not much accuracy at all.
I have been trying for about an hour to get the Garmin to pick up the Power sensor but it will not detect it.
I did the firmware beta update via the nRF software but it just will not even see the sensor.
I am pedaling and trying over and over and the Garmin just won't detect it.
I have tried unplugging and plugging it back in. I see a red light for a few seconds but then it goes off.
Zwift sees the DFC not my Garmin does not. Is there something I am doing wrong?

UPDATE: I finally have got it to connect but am I correct in understanding that it will not detect speed?

veneman, 2024-11-18:
The firmware that DFC ships with only broadcasts power and cadence data to make it compatible with as many devices as possible. The[ beta release](https://github.com/intelligenate/dfc/releases/tag/speed-cadence-beta.1) broadcasts only speed and cadence but not power. We've done some work on an update that does power, speed, and cadence but have found that not all devices pick up on all of those bits of data.

Closed 2024-11-18.

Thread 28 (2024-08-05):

Output not displaying on Peloton

infinus, 2024-08-05:
I have connected the DFC as instructed to my Peloton, I do not have the bike+ just the regular bike. Initially I had the error on screen to verify connections, I verified connections and it did not go away but rebooting the peloton caused the error to go away but still no data displayed on the screen.

I can see power output on Apple Watch but no output on the Peloton screen. If I swap the connections on the DFC no more output it shown on either my Apple Watch nor my screen until I swap back at which point only my watch shows output. I have tried using another 3.5mm cable with the same results.

I also tried a firmware update on the DFC with no change in behavior. Rebooted everything no change. Peloton Version 2.6.2429.2062429

I suppose it could be a physical port issue with the device but it is brand new out of the box.

infinus, 2024-08-06:
I did some more testing, it still only sends data to external device in one orientation with the peloton plugged in to port near USB C port. My DFC has only 1 USB-C not two like mentioned elsewhere.

 Bike > DFC port near USB-C > Screen: Only data on Apple Watch
 Bike > DFC port on side > Screen: No data on screen nor Apple Watch
Bike > DFC port near USBC > not attached to screen: No data on screen nor Apple Watch/

so at some level the 3.5mm port on the Side is needed and detects but still not sure why it only works in one orientation. Not sure if this is due to peloton updating their software?

The connection error still displays from time to time along with a call customer support message but at least I can still get data on the watch.

infinus, 2024-08-20:
@veneman is this project still active or should I reach out to crowd supply about a refund? I’d love to use the product but not very useful as is.

Closed 2024-11-18.

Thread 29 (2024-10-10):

Support speed/cadence/power for Fenix devices?

ChristopherS-github, 2024-10-10:
Hi,

I was wondering if it would be possible to provide a firmware providing all three of speed/cadence/power instead of choosing for two of them. Is that technically possible?

chris-mosley, 2025-03-08:
I know this has sat for a while but if we can't have all three another option I'd like to have would be power+speed.  Then I could just use the Garmin cadence sensor to have all of them.

Trebuin, 2025-03-11:
Could you please release it, but please make sure we have a way to roll back to the current working firmware.  I’d like to submit it as part of the Garmin Test team…it may be fixable on the Garmin side.
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

chris-mosley, 2025-03-11:
Oof.  Yeah that's unfortunate, but not the first time I've run into these kinds of shenanigans with Garmin.  I have a Fenix 8 so if you need testers I can help there.

So by wireless standard you're talking about bluetooth le?  I'm not sure how flexible the device is.  Would it be possible to present as a speed sensor and a power sensor separately?

ChristopherS-github, 2025-04-07:
Assuming that the 'fitness machine' protocol is not an option for the Garmin Fenix watches, I was wondering what a workaround might be for the user. Can one buy two DFCs, connect both, and configure one for power+cadence and one for speed+cadence? Would that work?
Or can one DFC act as two, so to say?

Closed 2025-03-11.

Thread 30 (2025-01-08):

No data on Peloton - solved

Vr6TypeR, 2025-01-08:
Wanted to document this in case anyone is running into the same problem.

First off, everywhere that I say "audio" in here, it's really the data cable. The jack is a headphone jack, so I refer to is as audio.

Had been using DFC for a while with no problem, connected to Peloton, outputting to Garmin, occasionally to Zwift.
Suddenly started seeing a Peloton message "ensure cables are connected" and no data on screen.
Found that data was coming into the DFC, I could see it on the GARMIN, but it wasn't going back out to the Peloton.
Switched the (audio cable) connections from long side to short side and lost all data completely (even to Garmin)
Concluded one of the audio ports on the DFC went bad.
Had an audio splitter cable (audio Y) kicking around, so I used it to connect 1 end to the DFC input (the good port) and the other 2 ends of the Y cable went 1 up to the Peloton, the other to the Peloton cable.   This worked. basically split the signal from the peloton cable into 2, one up to the screen, and one over to the DFC.

Finally had some time to look at the DFC board, I took it out of the enclose (always handle the board by the edges only), and had a look at the connectors.
Found a lifted pad on of the audio (data) jack.
After talking to my wife, turns out she had swivelled the screen and had bent the DFC cables between the screen and the mount, just before the DFC stopped working for me.

If anyone out there is having similar problems, check your cables,  use an audio splitter cable, or if you're slightly technical, take the board out and have a look at it for damaged audio jacks.
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

I was lucky enough to be able to solder the bad back down to the trace right beside it. Could have been worse.

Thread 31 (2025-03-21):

DRC Connected but no Power or Cadence Data in Zwift

Bharzog, 2025-03-21:
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

Per the first screen shot, power and cadence data show up on the Peloton tablet while doing a "Just Ride"

Per the second screen shot, DFC shows as a source for Power and Cadence, but no Power or Cadence data show up.

I have tried restarting everything and tried unplugging and re-plugging the cables.

Bharzog, 2025-03-22:
Just to make sure that it was not a Zwift issue, I downloaded Rouvy and set it up to use DFC for Power and cadence. Same issue. It shows a connected, but there is no data for Watts and Cadence.

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

veneman, 2025-03-25:
Showing data on the just ride screen but nothing through DFC is something I haven't seen before. Occasionally there's a bad connector or cable but in that case you wouldn't get data on the bike screen.

Do you have the data cable going through DFC as shown here
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 or here?
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

In any case, we'll get you sorted either with some new cables or swap out your DFC. Send an email to info@intelligenate.com and we'll take it from there.

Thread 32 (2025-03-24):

Pairing with Garmin Forerunner 965

dangermccann, 2025-03-24:
Has anyone had any luck getting DFC to work with Garmin Forerunner 965? I see other Forerunner models listed in the compatibility table, but the 965 wasn't listed. When adding a new sensor on the Garmin it is able to discover the DFC, but pairing with the sensor always seems to fail. I've tried the two beta firmware versions as well with the same result. Any help would be appreciated.

veneman, 2025-03-25:
The 965 should work fine since it says it's compatible with power meters but we haven't tested it specifically. Here's a few things to check.

- Have you tried connecting DFC to any other devices or apps? Kinomap or Zwift are pretty easy to get up and running quickly with DFC.
- Have you connected any other power meters to your watch?
- When you power on DFC do you see a red light blinking through the ports for the first few minutes?
- What are you using to power DFC? It works best using the cable that it comes with it. Using USB-C to USB-C cables can cause issues since DFC draws so little power that some USB-C chargers shut off power to it.

dangermccann, 2025-04-05:
Thank you for the response.  I'm not sure what I did differently today, but I was able to successfully pair and use the device during a workout.  Thanks again.

Closed 2025-04-05.

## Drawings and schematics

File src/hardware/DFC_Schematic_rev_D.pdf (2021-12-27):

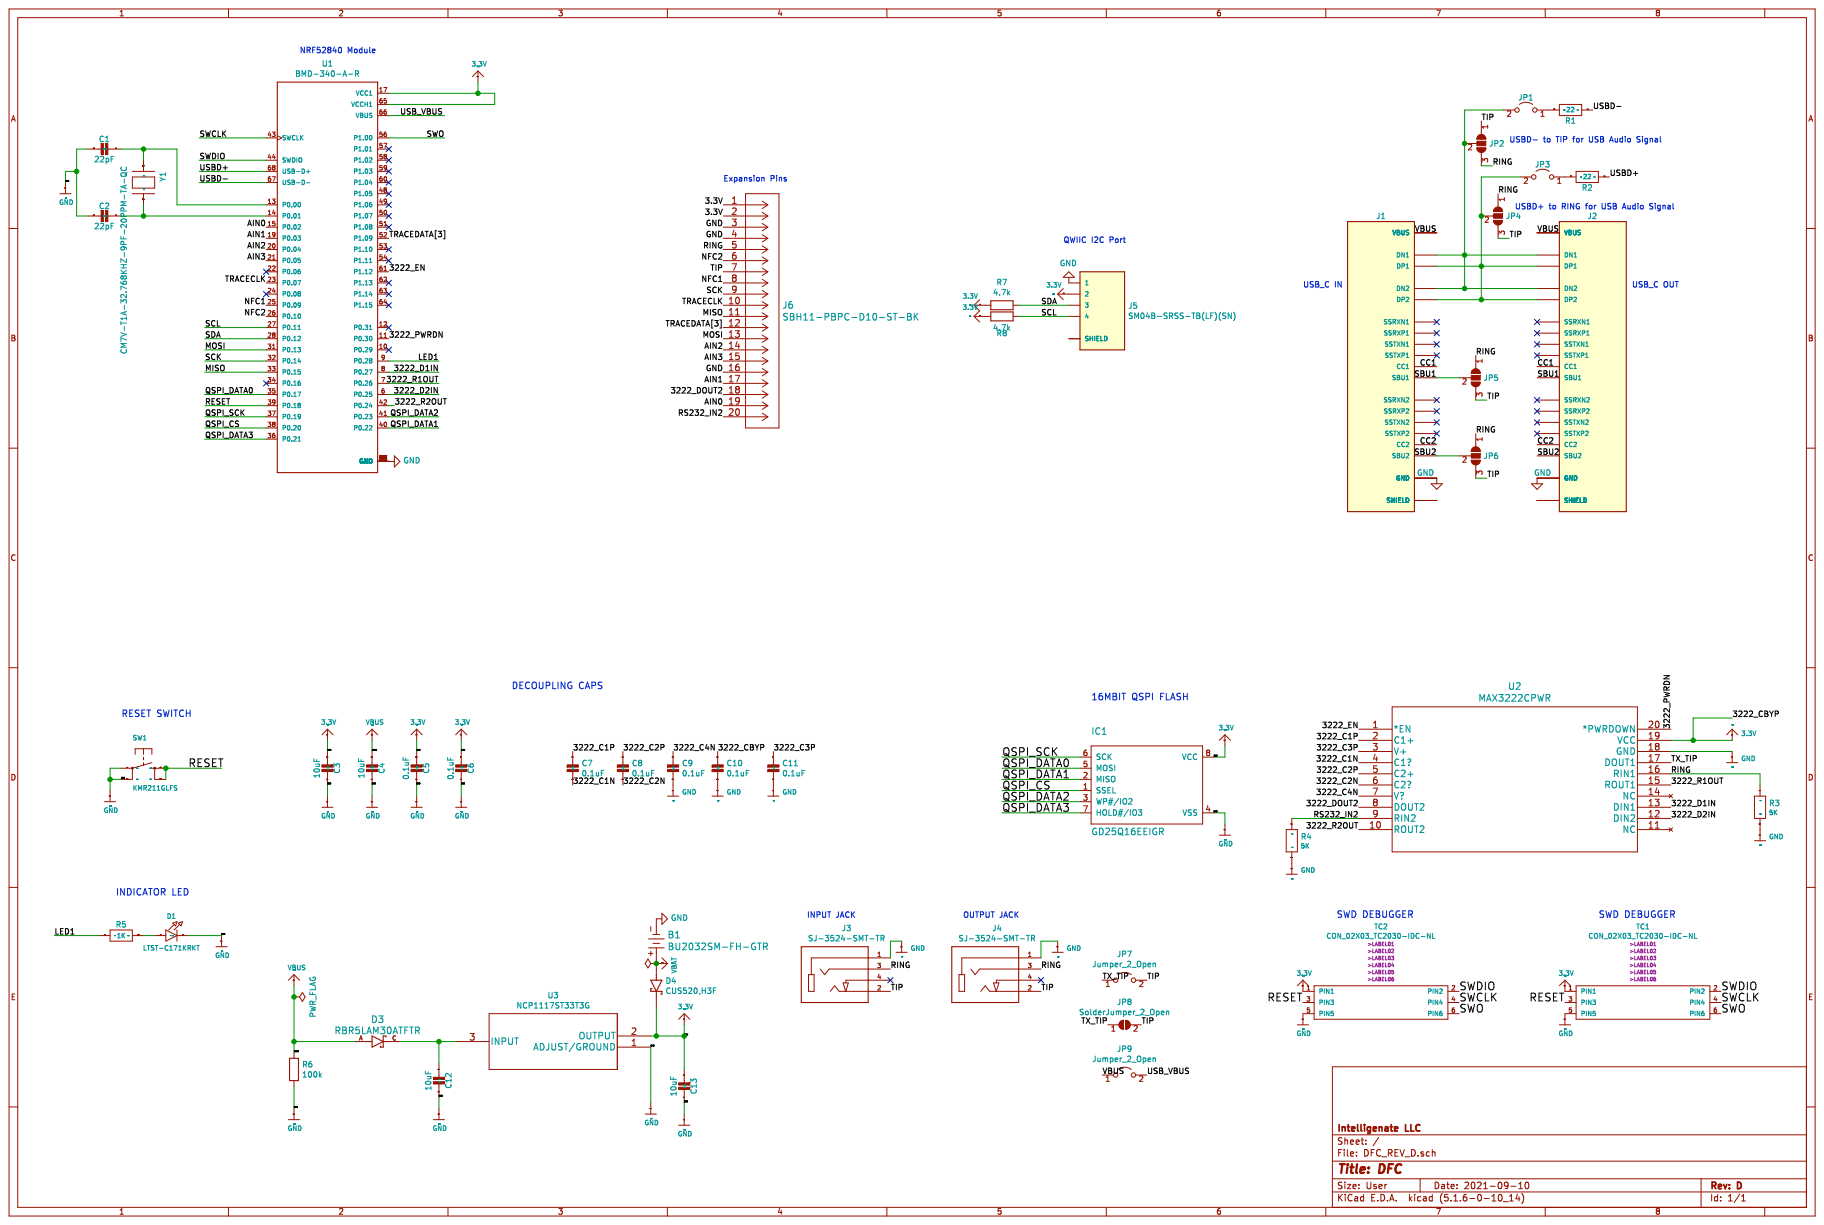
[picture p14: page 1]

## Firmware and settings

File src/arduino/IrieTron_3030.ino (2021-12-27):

/*********************************************************************
 BLE cycling power service
 
 Reads the data stream from a Peloton bike and broadcasts it as a cycling power service (for connection 
 to wearable devices) or a fitness machine (for connection to apps like Zwift).
 Adapted from Adafruit's heart rate example service for nRF52 based Bluefruit LE modules.

Copyright 2021 Intelligenate LLC

Licensed under the Apache License, Version 2.0 (the "License");
you may not use this file except in compliance with the License.
You may obtain a copy of the License at

    http://www.apache.org/licenses/LICENSE-2.0

Unless required by applicable law or agreed to in writing, software
distributed under the License is distributed on an "AS IS" BASIS,
WITHOUT WARRANTIES OR CONDITIONS OF ANY KIND, either express or implied.
See the License for the specific language governing permissions and
limitations under the License.
*********************************************************************/
#include <bluefruit.h>
#include <Arduino.h>
#include <Adafruit_NeoPixel.h>
#include <stdint.h>

#define UUID16_SVC_FITNESS_MACHINE                      0x1826
//#define UUID16_CHR_FITNESS_MACHINE_STATUS               0x2ADA // not used
#define UUID16_CHR_FITNESS_MACHINE_FEATURE              0x2ACC
#define UUID16_CHR_INDOOR_BIKE_DATA                     0x2AD2
#define HEADER        0xF1
#define FOOTER        0xF6
#define CAD_ID        0x41
#define RES_ID        0x4A
#define POW_ID        0x44 
#define DEBUG         false
#define DEBUG_CAD     false
#define POW_CAD       false

// NeoPixel setup
#define NEOPIXEL_VERSION_STRING "Neopixel v2.0"
#define PIN                     PIN_NEOPIXEL   /* Pin used to drive the NeoPixels */
uint8_t components = 3;     // only 3 and 4 are valid values
uint8_t *pixelBuffer = NULL;
Adafruit_NeoPixel neopixel = Adafruit_NeoPixel(1, PIN, NEO_GRB + NEO_KHZ800);

/* Service Definitions from BLEUuid.h
 * Cycling Power Service:       0x1818
 */
BLEService        powerService = BLEService(UUID16_SVC_CYCLING_POWER);
BLECharacteristic powerMeasCharacteristic = BLECharacteristic(UUID16_CHR_CYCLING_POWER_MEASUREMENT);
BLECharacteristic powerFeatureCharacteristic = BLECharacteristic(UUID16_CHR_CYCLING_POWER_FEATURE);
BLECharacteristic sensorLocation = BLECharacteristic(UUID16_CHR_SENSOR_LOCATION);

BLEService        fitnessService = BLEService(UUID16_SVC_FITNESS_MACHINE);
BLECharacteristic fitnessFeatureCharacteristic = BLECharacteristic(UUID16_CHR_FITNESS_MACHINE_FEATURE);
BLECharacteristic indoorBikeDataCharacteristic = BLECharacteristic(UUID16_CHR_INDOOR_BIKE_DATA);

BLEService        cyclingSpeedCadService = BLEService(UUID16_SVC_CYCLING_SPEED_AND_CADENCE);
BLECharacteristic cyclingSpeedCadFeature = BLECharacteristic(UUID16_CHR_CSC_FEATURE);
BLECharacteristic cyclingSpeedCadMeasurement = BLECharacteristic(UUID16_CHR_CSC_MEASUREMENT);

BLEDis bledis;    // DIS (Device Information Service) helper class instance
BLEBas blebas;    // BAS (Battery Service) helper class instance

int16_t prevPower = 100;  // Used for randomWalk
float revCount = 0;
uint16_t lastRevTime = 0;
uint32_t wheelRevs = 0;
long lastNotify = millis();

// Struct to hold and return power and cadence measurements
struct powerAndCadence {
  int16_t power;
  int16_t cadence;
  int16_t resistance;
  bool powerValid;
  bool cadenceValid;
  bool resistanceValid;
}; 

struct powerAndCadence pAndC = {
  0,0,0,false,false,false
};

void setup()
{
  if(DEBUG){
    Serial.begin(115200);
    while ( !Serial ) delay(10);   // for nrf52840 with native usb
  
    Serial.println("Initializing the Coffee Cycling Meter");
    Serial.println("-----------------------\n");
  }

  // Config Neopixels
  neopixel.begin();
  neopixel.setPixelColor(0, neopixel.Color(0, 150, 0)); // Green
  neopixel.show();   // Send the updated pixel colors to the hardware.

  // Initialize the Bluefruit module with Peripheral = 2, Central = 0
//  Bluefruit.begin();
  Bluefruit.begin(3,0);

  Bluefruit.setName("Coffee");

  // Set the connect/disconnect callback handlers
  Bluefruit.Periph.setConnectCallback(connect_callback);
  Bluefruit.Periph.setDisconnectCallback(disconnect_callback);

  // Configure and Start the Device Information Service
  bledis.setManufacturer("Intelligenate Industries");
  bledis.setModel("Model 1");
  bledis.begin();

  // Start the BLE Battery Service and set it to 100%
  blebas.begin();
  blebas.write(100);

  // Setup the Cycling Power Meter service using
  // BLEService and BLECharacteristic classes
  setupCPM();

  // Setup the fitness machine service
  setupFTMS();

  // Setup the speed and cadence service
//  setupCSC();

  // Setup the advertising packet(s)
  startAdv();
  if(DEBUG){
    Serial.println("\nAdvertising");  
  }  

  Serial1.begin(19200);  //Serial rate of Peloton
}

void startAdv(void)
{
  // Advertising packet
  Bluefruit.Advertising.addFlags(BLE_GAP_ADV_FLAGS_LE_ONLY_GENERAL_DISC_MODE);
  
  
// Create service data bytes
//Service Data AD Type            UINT8   1  BLE_GAP_AD_TYPE_SERVICE_DATA 
//Fitness Machine Service UUID    UINT16  2  UUID16_SVC_FITNESS_MACHINE
//Flags                           UINT8   1  0x01 == Fitness Machine Available
//Fitness Machine Type            UINT16  2  0x20 == bit5 == 1, Indoor bike supported

const uint8_t serviceData[5] = {highByte(UUID16_SVC_FITNESS_MACHINE),lowByte(UUID16_SVC_FITNESS_MACHINE),0x01,0x00,0x20};
//const uint8_t serviceData[5] = {0x20,0x00,0x01,highByte(UUID16_SVC_FITNESS_MACHINE),lowByte(UUID16_SVC_FITNESS_MACHINE)};
//const uint8_t serviceData[5] = {lowByte(UUID16_SVC_FITNESS_MACHINE),highByte(UUID16_SVC_FITNESS_MACHINE),0x01,0x20,0x00}; // doesn't work
  Bluefruit.Advertising.addData(BLE_GAP_AD_TYPE_SERVICE_DATA, &serviceData, 5); // sizeof(fitnessMachineType) //Indoor bike supported
  
  Bluefruit.Advertising.addTxPower();

  
  Bluefruit.Advertising.addService(fitnessService);
//  Bluefruit.Advertising.addService(cyclingSpeedCadService);
  Bluefruit.Advertising.addService(powerService);

  // Include Name
  Bluefruit.Advertising.addName();
  
  /* Start Advertising
   * - Enable auto advertising if disconnected
   * - Interval:  fast mode = 20 ms, slow mode = 152.5 ms
   * - Timeout for fast mode is 30 seconds
   * - Start(timeout) with timeout = 0 will advertise forever (until connected)
   * 
   * For recommended advertising interval
   * https://developer.apple.com/library/content/qa/qa1931/_index.html   
   */
  Bluefruit.Advertising.restartOnDisconnect(true);
  Bluefruit.Advertising.setInterval(32, 244);    // in unit of 0.625 ms
  Bluefruit.Advertising.setFastTimeout(30);      // number of seconds in fast mode
  Bluefruit.Advertising.start(0);                // 0 = Don't stop advertising after n seconds  
}

void setupCPM(void)
{
  // Configure the Cycling Power service
  powerService.begin();

  // Note: You must call .begin() on the BLEService before calling .begin() on
  // any characteristic(s) within that service definition.. Calling .begin() on
  // a BLECharacteristic will cause it to be added to the last BLEService that
  // was 'begin()'ed!

  // Configure the Cycling Power Measurement characteristic
  // Properties = Notify
  // Min Len    = 1
  // Max Len    = 8
  //    B0:1    = UINT16  - Flag (MANDATORY)
  //       b5   = Crank Revolution Data Present
  //    B2:3      = SINT16  - 16-bit Instantaneous Power
  powerMeasCharacteristic.setProperties(CHR_PROPS_NOTIFY);
  powerMeasCharacteristic.setPermission(SECMODE_OPEN, SECMODE_NO_ACCESS);
  if(POW_CAD){
    powerMeasCharacteristic.setFixedLen(8);  // for power and cadence
  } else{
    powerMeasCharacteristic.setFixedLen(4);  // for power only
  }
  powerMeasCharacteristic.setCccdWriteCallback(cccd_callback);  // Optionally capture CCCD updates
  powerMeasCharacteristic.begin();


//    uint16_t powerData[4]; // for power and cadence
//    powerData[0] = 32; // Set the flags, 00100000 - 32  - 0x020 - Crank Revolution Data Present

  uint16_t powerData[2]; // for power only
  powerData[0] = 0; // Set the flags, power only

  powerData[1] = 0; // Power
  powerData[2] = 0; // Crank revs
  powerData[3] = 0; // time
  powerMeasCharacteristic.write(powerData, sizeof(powerData));  //data,length

  // Configure the cycling power feature characteristic
  powerFeatureCharacteristic.setProperties(CHR_PROPS_READ);
  powerFeatureCharacteristic.setPermission(SECMODE_OPEN, SECMODE_NO_ACCESS);
  powerFeatureCharacteristic.setFixedLen(4);
  powerFeatureCharacteristic.begin();
  
//  uint8_t featureFlag[4] = {0,0,0,8}; // for power and cadence
  
  uint8_t featureFlag[4] = {0,0,0,0};  // works for just power
  
  powerFeatureCharacteristic.write(featureFlag,4);  //(data,length) data is 32bit flag with bit 3 on "index="3" size="1" name="Crank Revolution Data Supported""

  // Configure the Sensor Location characteristic
  // Properties = Read
  // Min Len    = 1
  // Max Len    = 1
  //    B0      = UINT8 - Sensor Location
  //      9     = Front Hub location - doesn't really matter
  sensorLocation.setProperties(CHR_PROPS_READ);
  sensorLocation.setPermission(SECMODE_OPEN, SECMODE_NO_ACCESS);
  sensorLocation.setFixedLen(1);
  sensorLocation.begin();
  sensorLocation.write8(9);    // Set the characteristic to 'Front Hub' (9)

  
}

/**
 * <Field name="CSC Feature">
            <Requirement>Mandatory</Requirement>
            <Format>16bit</Format>
            <BitField>
                <Bit index="0" size="1" name="Wheel Revolution Data Supported">
                    <Enumerations>
                        <Enumeration key="0" value="False" />
                        <Enumeration key="1" value="True" />
                    </Enumerations>
                </Bit>
                <Bit index="1" size="1" name="Crank Revolution Data Supported">
                    <Enumerations>
                        <Enumeration key="0" value="False" />
                        <Enumeration key="1" value="True" />
                    </Enumerations>
                </Bit>
                <Bit index="2" size="1" name="Multiple Sensor Locations Supported">
                    <Enumerations>
                        <Enumeration key="0" value="False" />
                        <Enumeration key="1" value="True" />
                    </Enumerations>
                </Bit>
                <ReservedForFutureUse index="3" size="13" />
            </BitField>
        </Field>
 */
void setupCSC(void)
{
  // Configure the Cycling Power service
  cyclingSpeedCadService.begin();

  // Note: You must call .begin() on the BLEService before calling .begin() on
  // any characteristic(s) within that service definition.. Calling .begin() on
  // a BLECharacteristic will cause it to be added to the last BLEService that
  // was 'begin()'ed!

  // Configure the Cycling Speed and Cadence Measurement characteristic
  cyclingSpeedCadMeasurement.setProperties(CHR_PROPS_NOTIFY);
  cyclingSpeedCadMeasurement.setPermission(SECMODE_OPEN, SECMODE_NO_ACCESS);
  cyclingSpeedCadMeasurement.setFixedLen(7);  // for speed only
  cyclingSpeedCadMeasurement.setCccdWriteCallback(cccd_callback);  // Optionally capture CCCD updates
  cyclingSpeedCadMeasurement.begin();

  uint8_t speedData[7]; // for speed only
  speedData[0] = 0x01; // Set the flags, speed only
  speedData[1] = 0; // Wheel Revolutions
  speedData[2] = 0; // Wheel Revolutions
  speedData[3] = 0; // Wheel Revolutions
  speedData[4] = 0; // Wheel Revolutions
  speedData[5] = 0; // Last Wheel Event Time
  speedData[6] = 0; // Last Wheel Event Time
  cyclingSpeedCadMeasurement.write(speedData, sizeof(speedData));  //data,length

  // Configure the cycling power feature characteristic
  cyclingSpeedCadFeature.setProperties(CHR_PROPS_READ);
  cyclingSpeedCadFeature.setPermission(SECMODE_OPEN, SECMODE_NO_ACCESS);
  cyclingSpeedCadFeature.setFixedLen(2);
  cyclingSpeedCadFeature.begin();
  
  uint8_t featureFlag[2] = {0,0x01};  
  
  cyclingSpeedCadFeature.write(featureFlag,2);  //(data,length) data is 16bit flag with bit 1 on name="Wheel Revolution Data Supported"
}

/**
   * Fitness machine flags (16 bits):
   * Instantaneous Speed (bit 0 = 0)
   * Instantaneous Cadence (bit 2)
   * Resistance Level Present (bit 5)
   * Instantaneous Power Present (bit 6)
   * 
   * Fitness Machine Features Field (32 bits)
   * Cadence Supported (bit 1)
   * Resistance Level Supported (bit 7)
   * Power Measurement Supported (bit 14)
   * 
   * Fitness Machine Type Field (16 bits)
   * Indoor Bike Supported (bit 5)
   * 
   
 */
void setupFTMS(void){
   fitnessService.begin();

     // Configure the indoor bike data characteristic
  // See: TODO
  // Properties = Notify
  // Min Len    = 1
  // Max Len    = 8
  //    B0:1    = UINT16  - Flag (MANDATORY)
  //       b5   = Crank Revolution Data Present
  //    B2:3      = SINT16  - 16-bit Instantaneous Power
  indoorBikeDataCharacteristic.setProperties(CHR_PROPS_NOTIFY);
  indoorBikeDataCharacteristic.setPermission(SECMODE_OPEN, SECMODE_NO_ACCESS);
  indoorBikeDataCharacteristic.setFixedLen(10);  // TODO figure out length, 4 per measurement?
  indoorBikeDataCharacteristic.setCccdWriteCallback(cccd_callback);  // Optionally capture CCCD updates
  indoorBikeDataCharacteristic.begin();

  // Flag size is 16 bit
  uint16_t indoorBikeData[10]; // TODO Figure out size, 2 per measurement?
  indoorBikeData[0] = 0x64;//01100100; // Set the flags, instantaneous speed (bit 0=0), instantaneous cadence (bit 2), resistance (bit 5), instantaneous power (bit 6)
  indoorBikeData[1] = 0; // Speed, uint16, Kilometer per hour with a resolution of 0.01
  indoorBikeData[2] = 0; // Cadence, uint16, 1/minute with a resolution of 0.5
  indoorBikeData[3] = 0; // Resistance, sint16, Unitless with a resolution of 1
  indoorBikeData[4] = 0; // Power, sint16, Watts with a resolution of 1
//  indoorBikeData[5] = 0; // 
//  indoorBikeData[6] = 0; // 
//  indoorBikeData[7] = 0; // 
  indoorBikeDataCharacteristic.write(indoorBikeData, sizeof(indoorBikeData));  //data,length


  // Configure the fitness feature characteristic
  // From 4.3.1 Characteristic Behavior
  // fitness machine features field is 32 bits and are set below
  // target settings field is 32 bits but all are set to 0
  fitnessFeatureCharacteristic.setProperties(CHR_PROPS_READ);
  fitnessFeatureCharacteristic.setPermission(SECMODE_OPEN, SECMODE_NO_ACCESS);
  fitnessFeatureCharacteristic.setFixedLen(4);
  fitnessFeatureCharacteristic.begin();
  //1 Cadence Supported
  //7 Resistance Level Supported
  //14 Power Measurement Supported
  // uint8_t featureFlag[4] = {0,0,0x40,0x82};  // 2x 32bit flag
//  uint8_t featureFlag[4] = {0x82,0x40,0,0};  // 2x 32bit flag
//  uint8_t featureFlag[4] = {0x40,0x82,0,0};  // 2x 32bit flag
  uint8_t featureFlag[4];  // 2x 32bit flag
  featureFlag[0] = 0x82;
  featureFlag[1] = 0x40;
  featureFlag[2] = 0x00;
  featureFlag[3] = 0x00;
//  uint8_t featureFlag[4] = {0,0,0,8}; // for power and cadence
  fitnessFeatureCharacteristic.write(featureFlag, sizeof(featureFlag));  //(data,length) data is 32bit flag with bit 3 on "index="3" size="1" name="Crank Revolution Data Supported""
}


void connect_callback(uint16_t conn_handle)
{
  // Get the reference to current connection
  BLEConnection* connection = Bluefruit.Connection(conn_handle);

  char central_name[32] = { 0 };
  connection->getPeerName(central_name, sizeof(central_name));

  if(DEBUG){
    Serial.print("Connected to ");
    Serial.println(central_name);  
  }
}

/**
 * Callback invoked when a connection is dropped
 * @param conn_handle connection where this event happens
 * @param reason is a BLE_HCI_STATUS_CODE which can be found in ble_hci.h
 */
void disconnect_callback(uint16_t conn_handle, uint8_t reason)
{
  (void) conn_handle;
  (void) reason;

  if(DEBUG){
    Serial.print("Disconnected, reason = 0x"); Serial.println(reason, HEX);
    Serial.println("Advertising!");  
  }
}


void cccd_callback(uint16_t conn_hdl, BLECharacteristic* chr, uint16_t cccd_value)
{
    if(DEBUG){
      // Display the raw request packet
      Serial.print("CCCD Updated: ");
      //Serial.printBuffer(request->data, request->len);
      Serial.print(cccd_value);
      Serial.println("");
    }

    // Check the characteristic this CCCD update is associated with in case
    // this handler is used for multiple CCCD records.
    if (chr->uuid == powerMeasCharacteristic.uuid) {
        if (chr->notifyEnabled(conn_hdl)) {
          if(DEBUG){
            Serial.println("Cycling Power Measurement 'Notify' enabled");
          }
        } else {
          if(DEBUG){
            Serial.println("Cycling Power Measurement 'Notify' disabled");
          }
        }
    }

    if (chr->uuid == fitnessFeatureCharacteristic.uuid) {
        if (chr->notifyEnabled(conn_hdl)) {
          if(DEBUG){
            Serial.println("Cycling Power Measurement 'Notify' enabled");
          }
        } else {
          if(DEBUG){
            Serial.println("Cycling Power Measurement 'Notify' disabled");
          }
        }
    }
}
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
void loop()
{
  digitalToggle(LED_RED);
  
  if ( Bluefruit.connected() ) {
    
//    int16_t power = (int16_t) randomWalk();  // for testing

    pAndC = readPower();
    if((pAndC.powerValid != true) && (pAndC.cadenceValid != true)){
      if(DEBUG){
        Serial.print("***** Invalid measurement. Power valid: ");
        Serial.print(pAndC.powerValid);
        Serial.print(" Cadence valid: ");
        Serial.println(pAndC.cadenceValid);
      }
      return;
    }


    if(DEBUG_CAD){
      Serial.print("lastRevTime: ");
      Serial.print(lastRevTime);
    }
    //TODO don't need to do this for fitness machine service, remove or make toggle to reduce computation
    unsigned long now = millis();
    unsigned long time1024 = floor(now*1e3/1024);
    unsigned long revTime = time1024 % 65536;  // roll over every 64 seconds
    uint16_t intRevTime = int(revTime);
    uint16_t revTimeDiff = intRevTime - lastRevTime;
    revCount = (pAndC.cadence * revTimeDiff)/60000.0 + revCount;
    uint16_t intRevCount = int(revCount);
    lastRevTime = intRevTime;

    if(DEBUG_CAD){
      Serial.print(" RevTimeDiff: ");
      Serial.print(revTimeDiff);
      Serial.print(" intRevTime: ");
      Serial.print(intRevTime);
      Serial.print(" revCount: ");
      Serial.print(revCount);
      Serial.print(" revCount int: ");
      Serial.println(intRevCount); 
    }
    

//    uint16_t powerData[4] = {0b00100000, power, revCount, intRevTime};  // flags, power, crank revs, time
    uint16_t powerData[4];
    if(POW_CAD){
      powerData[0] = 32; // flags = power and cadence  
    } else {
      powerData[0] = 0; // flags = power
    }
    powerData[1] = pAndC.power;
    powerData[2] = intRevCount;
    powerData[3] = intRevTime;
    powerData[4] = 0;
    powerData[5] = 0;
    powerData[6] = 0;
    powerData[7] = 0;

    uint16_t fitnessData[10];
    fitnessData[0] = 0x64; //01100100; // Set the flags, instantaneous speed (bit 0==0), instantaneous cadence (bit 2), resistance (bit 5), instantaneous power (bit 6)
    fitnessData[1] = 0; //speed in km/h with 0.01 resolution
    fitnessData[2] = pAndC.cadence << 1; 
    fitnessData[3] = pAndC.resistance;
    fitnessData[4] = pAndC.power;

    wheelRevs = wheelRevs + 1;  // 32bit cumulative wheel revolutions
    uint8_t speedData[7]; // for speed only
    speedData[0] = 0x01; // Set the flags, speed only
    speedData[1] = (wheelRevs >> 24) & 0xFF; // Wheel Revolutions
    speedData[2] = (wheelRevs >> 16) & 0xFF; // Wheel Revolutions
    speedData[3] = (wheelRevs >> 8) & 0xFF; // Wheel Revolutions
    speedData[4] = wheelRevs & 0xFF; // Wheel Revolutions
    speedData[5] = highByte(intRevTime); // Last Wheel Event Time
    speedData[6] = lowByte(intRevTime); // Last Wheel Event Time

   
    // Use .notify instead of .write
    // If it is connected but CCCD is not enabled
    // The characteristic's value is still updated although notification is not sent
    long timeToUpdate = millis() - lastNotify;
    if(timeToUpdate > 500){  // wait at least 0.5 seconds to update
       if(powerMeasCharacteristic.notify(powerData, sizeof(powerData))){
         lastNotify = millis();
         if(DEBUG){
           Serial.print("##### Power Measurement updated to: "); 
           Serial.print(pAndC.power); 
           Serial.print(", Cadence: "); 
           Serial.print(pAndC.cadence); 
           Serial.print(", Resistance: "); 
           Serial.println(pAndC.resistance); 
         }
        
       }else{
         if(DEBUG){
           Serial.println("Power ERROR: Notify not set in the CCCD or not connected!");        
         }
       }
     if(indoorBikeDataCharacteristic.notify(fitnessData, sizeof(fitnessData))){
       lastNotify = millis();
       if(DEBUG){
         Serial.print("FTMS Measurements updated to: "); 
         Serial.print(pAndC.power); 
         Serial.print(", Cadence: "); 
         Serial.print(pAndC.cadence); 
         Serial.print(", Resistance: "); 
         Serial.println(pAndC.resistance); 
       }
       
     }else{
       if(DEBUG){
         Serial.println("FTMS ERROR: Notify not set in the CCCD or not connected!");        
       }
     }
     if(cyclingSpeedCadMeasurement.notify(speedData, sizeof(speedData))){
       lastNotify = millis();
       if(DEBUG){
         Serial.print("Speed Measurements updated to: "); 
         Serial.print(wheelRevs);
         Serial.print(" wheel revs, intRevTime: ");
          Serial.println(intRevTime);
       }
       
     }else{
       if(DEBUG){
         Serial.println("FTMS ERROR: Notify not set in the CCCD or not connected!");        
       }
     }
    } else {
      if(DEBUG){
        Serial.print("timeToUpdate ");
        Serial.println(timeToUpdate);
      }
    }
  }
}

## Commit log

2021-12-27 Updated user guide and added design files
    [DFC_REV_D-B_Mask.gbs, DFC_REV_D-B_Paste.gbp, DFC_REV_D-B_SilkS.gbo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]
2022-01-21 Updated the user guide with more device compatibilities and FAQs
2022-01-27 Added note on FR245
    FR245 does not pick up power metrics, as the watch does not support reading power data. The FR245 can broadcast heart rate to the Edge 530, which can support power & cadence.
2023-03-01 Added power adapter link for Europe.
2024-02-05 Updated compatibility table with a note and link to the fix for certain Garmin devices.
